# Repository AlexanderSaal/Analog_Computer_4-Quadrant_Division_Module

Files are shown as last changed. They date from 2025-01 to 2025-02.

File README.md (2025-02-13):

# Analog Computer - 4-Quadrant Division Module
---

This repository provides a 4-Quadrant Division Module for analog computing applications. The design incorporates two independent 4-Quadrant Division circuits, each equipped with an output signal indicator and overload indicator to monitor operation. \
 The overload indicator activates if the output exceeds the machine unit of $\pm10V$ and the output signal indicator is red or green proportional to the negative or positive output voltage. This display enables easy diagnostic of an analog computing patch.

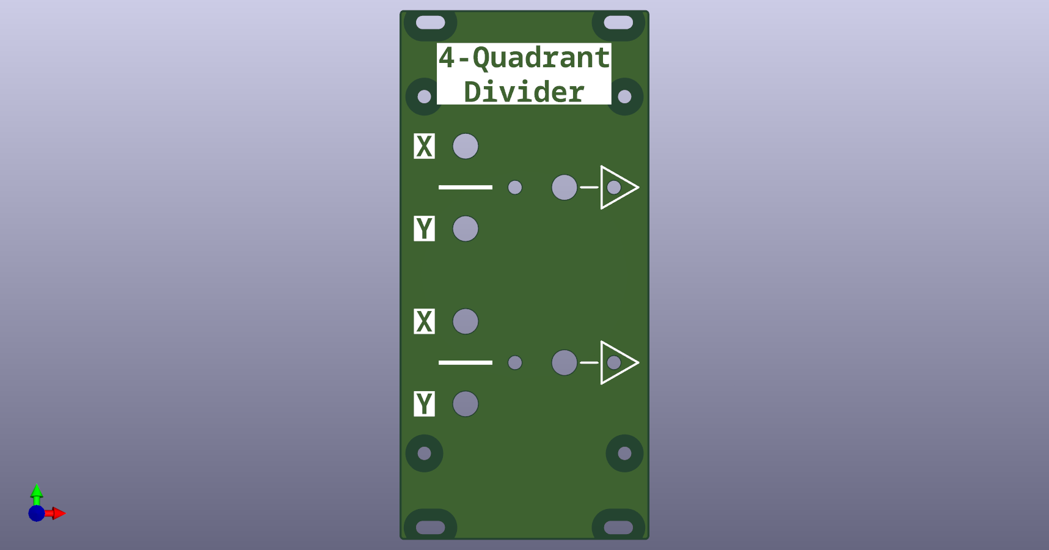
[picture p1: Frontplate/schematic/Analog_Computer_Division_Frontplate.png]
Front view of the Division Module


## Module Schematic

The schematic is divided into multiple sections for the ease of understanding. All functional modules like power management, division and error-indication have their own page in the circuit diagram.

<ins> 4-Quadrant Divider: </ins>\
The division is accomplished by having the multiplier in the feedback path of an operational amplifier, thus solving for $-X/|Y|$. To cover all 4 Quadrants of the input, we first have a section to get the absolute Value of of $Y$, which is fed into the division. The output then corrects for the sign of the input $Y$ and inverts the signal when needed. Thus the Output is $X/Y$, covering all 4 Quadrants of the input. To enable easy diagnostic and debugging of an analog patch, the LED indicator displays the polarity and size of the output signal.

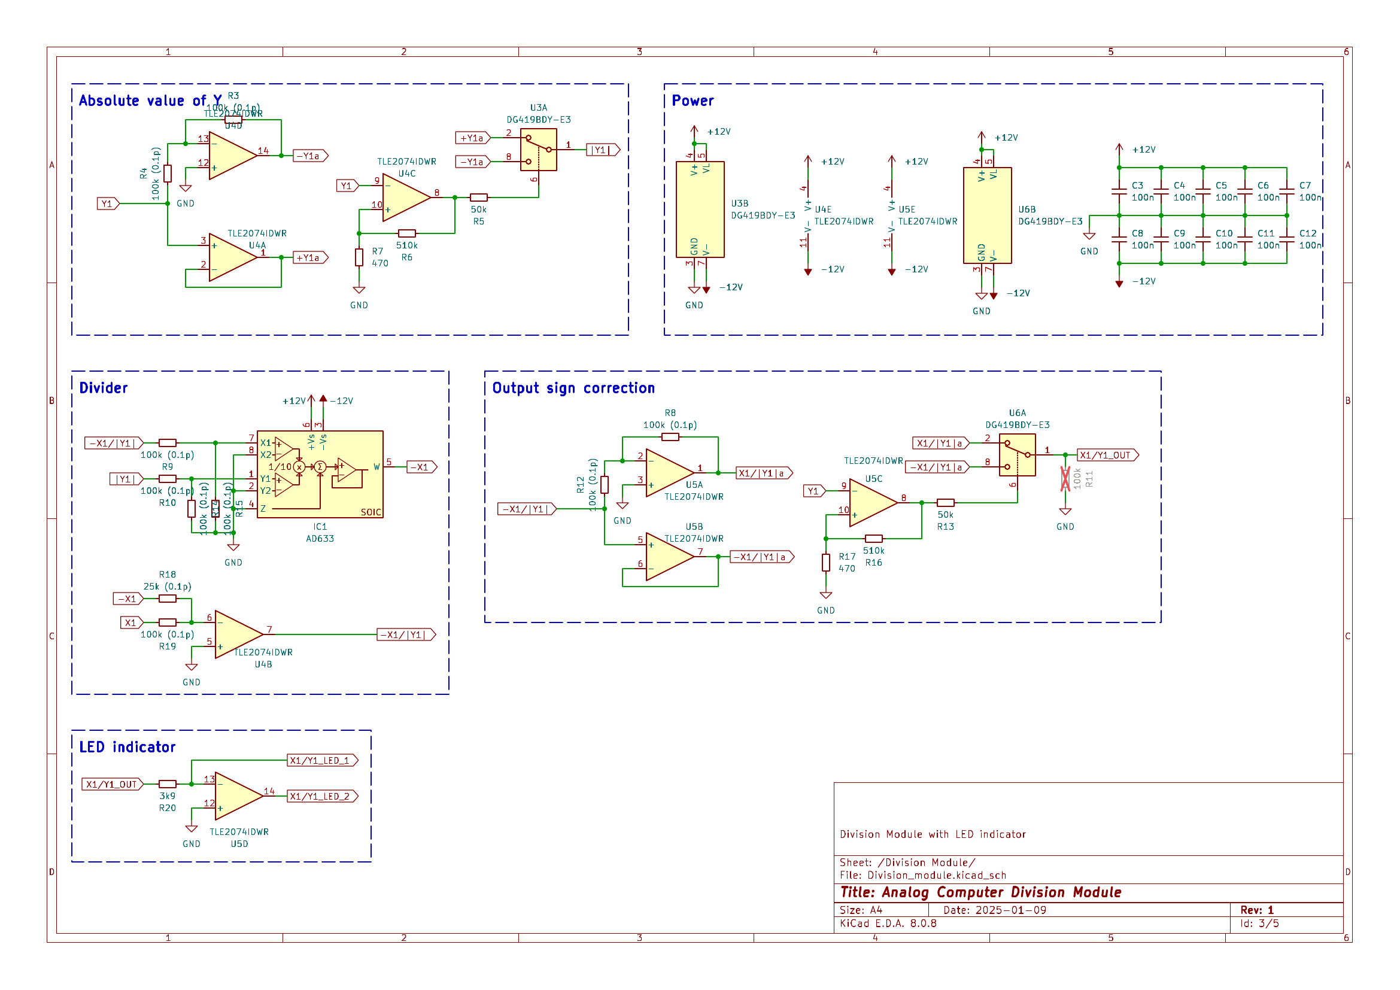
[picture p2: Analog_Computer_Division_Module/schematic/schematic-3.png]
Schematic of the Division Module Circuit implementation of the Division Module


<ins> Overload Indicator: </ins>\
The output signal of each seperate division circuit is compared to a reference voltage of $+10V$ and $-10V$. A red LED indicates the value of a division is exceeding the machine value of $\pm10V$. Which can easiliy happen when the absolute value of $Y$ gets small.

The Error Indicator for each individual Output takes a lot of extra space and components, but I consider it worth it for error hunting in an analog patch.

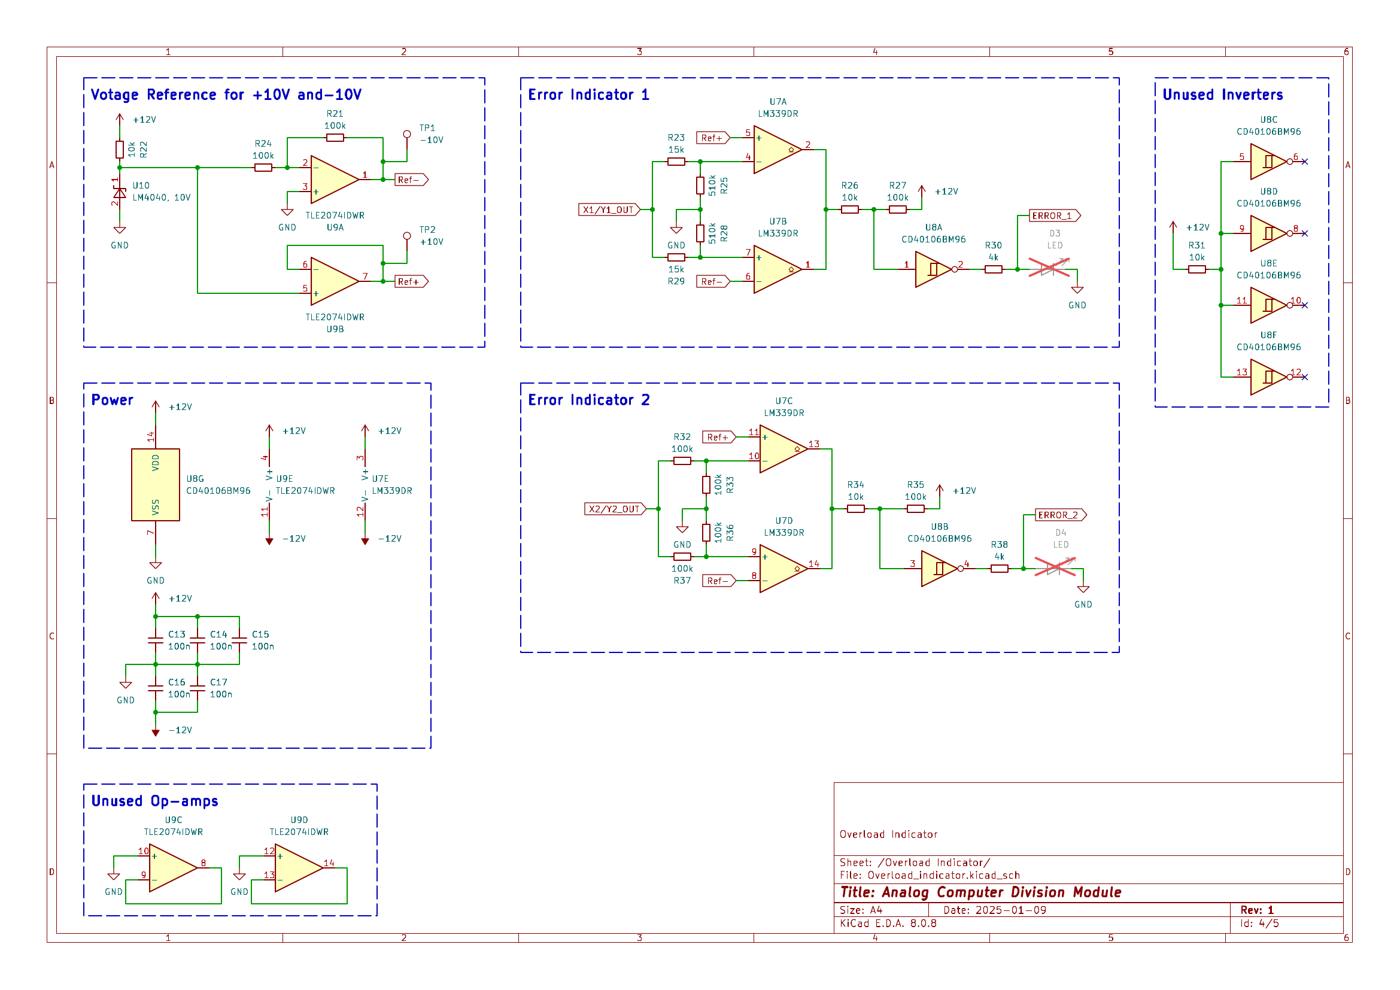
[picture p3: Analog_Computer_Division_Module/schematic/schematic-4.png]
Schematic of the Error Indicator Circuit implementation of the Error Indicator


<ins> References: </ins>\
The circuit is mostly based on the [THAT](https://the-analog-thing.org/) of [Anabrid GmbH](https://anabrid.com/), which has its circuit diagram openly available at their github repository [Anabrid](https://github.com/anabrid/the-analog-thing/tree/main). Also a special mention goes to Michael Koch who has put together a large collection of analog computing circuits in his [book on the THAT Analog Computer](http://www.astro-electronic.de/THAT_Analog_Computer_Book.pdf).

## BOM

**<ins>Main Module:</ins>** 

|Reference |Value |Footprint |QUANTITY|
|---|---|---|---|
|C1,C2 |10u |1206 / 3216Metric |2 |
|C3-C27 |100n |1206 / 3216Metric |25 |
|D1 |12V_GREEN |1206 / 3216Metric |1 |
|D2 |-12V_RED |1206 / 3216Metric |1 |
|IC1,IC2 |AD633 |SOIC-8 |2 |
|J1 |Conn_01x14_Pin |PinHeader_1x14_P2.54mm_Vertical|1 |
|J2 |Conn_02x05_Odd_Even|PinHeader_2x05_P2.54mm_Vertical|1 |
|Q1 |PMV250EPEA |SOT-23 |1 |
|Q2 |PMV450ENEA |SOT-23 |1 |
|R1,R2 |5k6 |1206 / 3216Metric |2 |
|R3,R4,R8-R10,R12,R14,R15,R19,R39,R40,R44-R46,R48,R50,R51,R55|100k (0.1p) |1206 / 3216Metric |18 |
|R5,R13,R41,R49 |50k |1206 / 3216Metric |4 |
|R6,R16,R25,R28,R42,R52 |510k |1206 / 3216Metric |6 |
|R7,R17,R43,R53 |470 |1206 / 3216Metric |4 |
|R18,R54 |25k (0.1p) |1206 / 3216Metric |2 |
|R20,R56 |3k9 |1206 / 3216Metric |2 |
|R21,R24,R27,R32,R33,R35-R37 |100k |1206 / 3216Metric |8 |
|R22,R26,R31,R34 |10k |1206 / 3216Metric |4 |
|R23,R29 |15k |1206 / 3216Metric |2 |
|R30,R38 |4k |1206 / 3216Metric |2 |
|U1,U2 |VCAN16A2 |SOT23-3 |2 |
|U3,U6,U11,U14 |DG419BDY-E3 |SOIC-8 |4 |
|U4,U5,U9,U12,U13 |TLE2074IDWR |SOIC-14 |5 |
|U7 |LM339DR |SOIC-14 |1 |
|U8 |CD40106BM96 |SOIC-14 |1 |
|U10 |LM4040, 10V |SOT-23 |1 |

**<ins>Middleplate:</ins>**

|Reference |Value |Footprint |QUANTITY|
|---|---|---|---|
|D1 |IND_X1/Y1 |LED_D3.0mm_FlatTop |1 |
|D2 |ERROR_1 |LED_D3.0mm_FlatTop |1 |
|D3 |IND_X2/Y2 |LED_D3.0mm_FlatTop |1 |
|D4 |ERROR_2 |LED_D3.0mm_FlatTop |1 |
|J1 |Conn_01x14_Socket  |PinSocket_1x14_P2.54mm_Vertical|1 |
|U1-U3 |VCAN16A2-03S-E3-08 |SOT23-3 |3 |

## List of special Components:

- OP-amp: [TLE2074IDWR](https://www.digikey.de/en/products/detail/texas-instruments/TLE2074IDWR/2799317) (Upgrade of the [TL074HIDR](https://www.digikey.de/en/products/detail/texas-instruments/TL074HIDR/13563033))
- analog IC switch: [DG456EY](https://www.digikey.de/en/products/detail/vishay-siliconix/DG456EY-T1-E3/1850020), [DG419BDY-E3](https://www.digikey.de/en/products/detail/vishay-siliconix/DG419BDY-E3/2621756), [DG403DYZ](https://www.digikey.de/en/products/detail/renesas-electronics-corporation/DG403DYZ/936160)
- 10V voltage reference: [LM4040CIM3-10.0/NOPB](https://www.digikey.de/en/products/detail/texas-instruments/LM4040CIM3-10-0-NOPB/363991)
- comparator: [LM339DR](https://www.digikey.de/en/products/detail/texas-instruments/LM339DR/276657)
- logic inverter: [CD40106BM96](https://www.digikey.de/en/products/detail/texas-instruments/CD40106BM96/525858)

Altnernatives to consider:
- Multiplier: [AD633JRZ](https://www.digikey.de/en/products/detail/analog-devices-inc/AD633JRZ/617831) to [AD835ARZ](https://www.digikey.de/en/products/detail/analog-devices-inc/AD835ARZ-REEL7/621103)

## License

This work is published under the [CERN Open Hardware Licence Version 2 - Strongly Reciprocal](LICENSE)

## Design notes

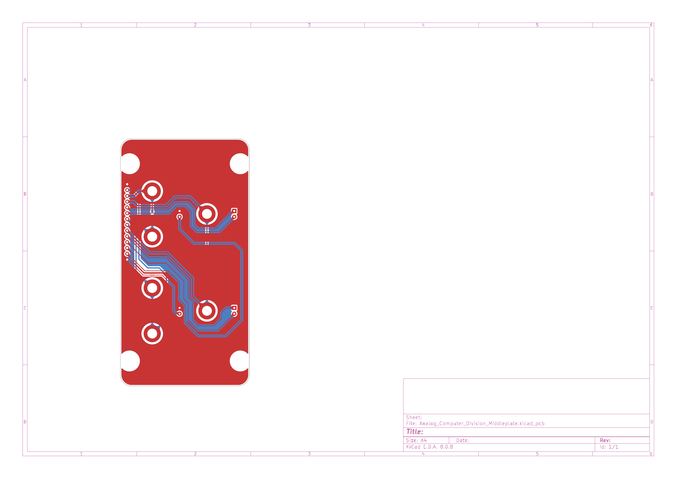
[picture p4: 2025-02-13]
Middleplate/schematic/PCB-1.png

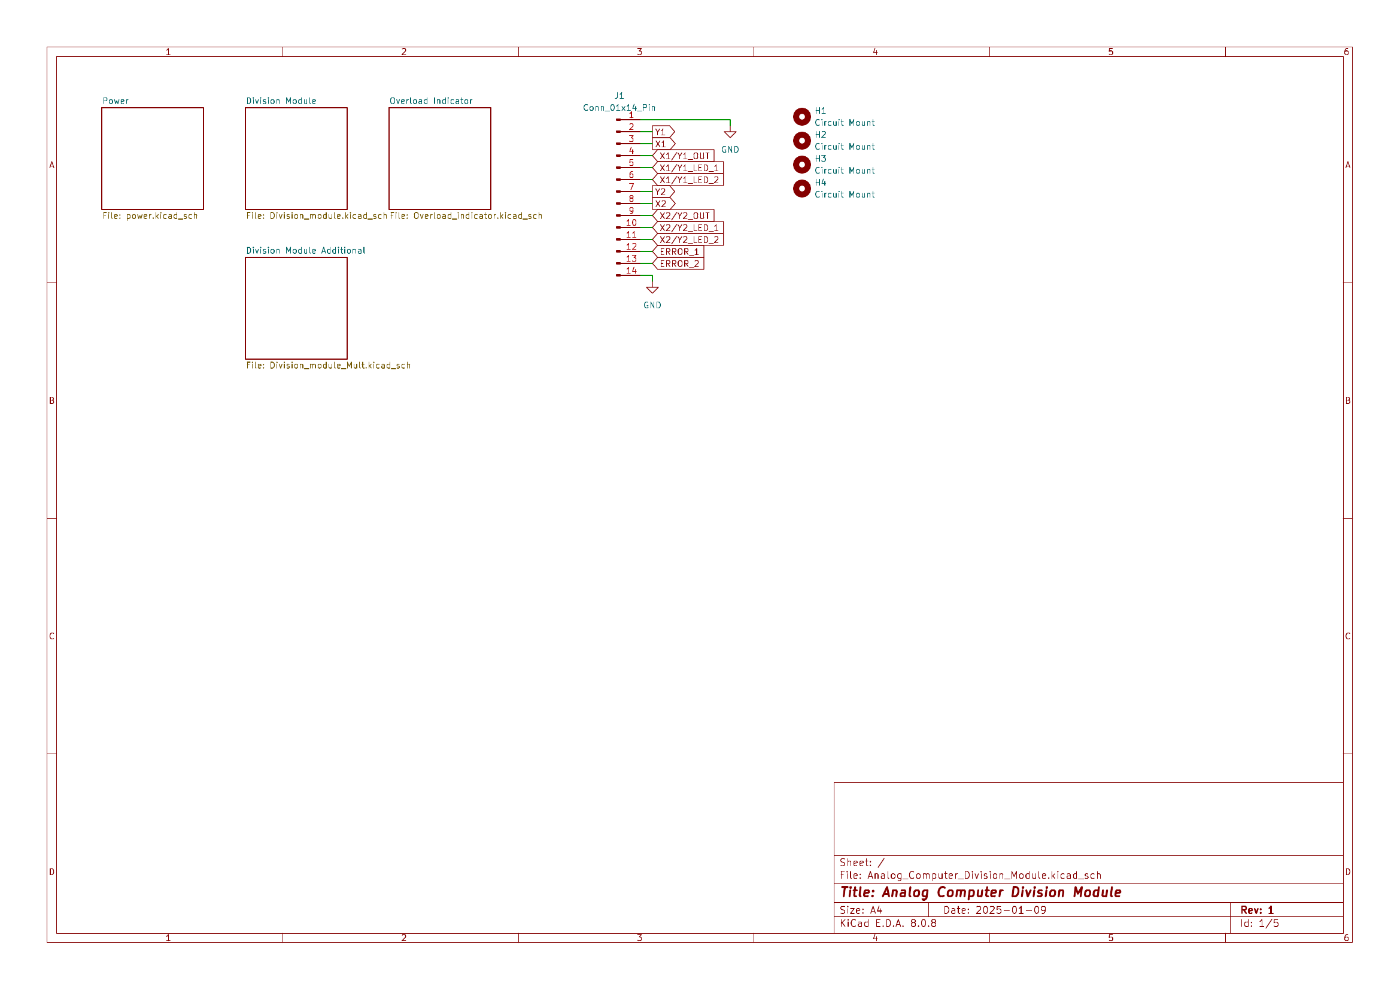
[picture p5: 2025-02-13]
Analog_Computer_Division_Module/schematic/schematic-1.png

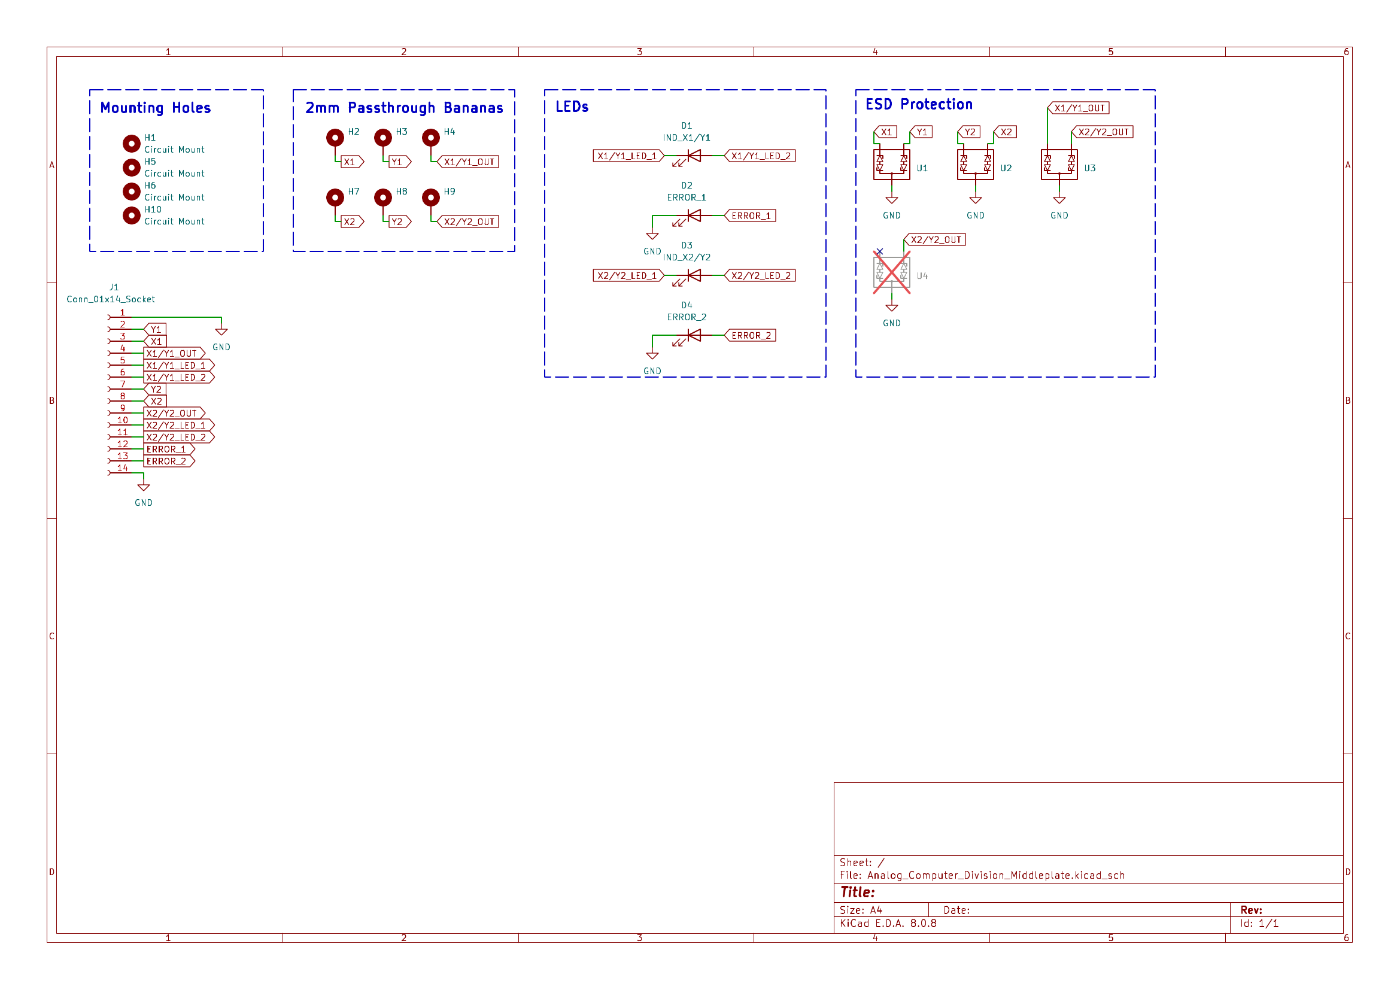
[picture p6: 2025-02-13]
Middleplate/schematic/schematic-1.png

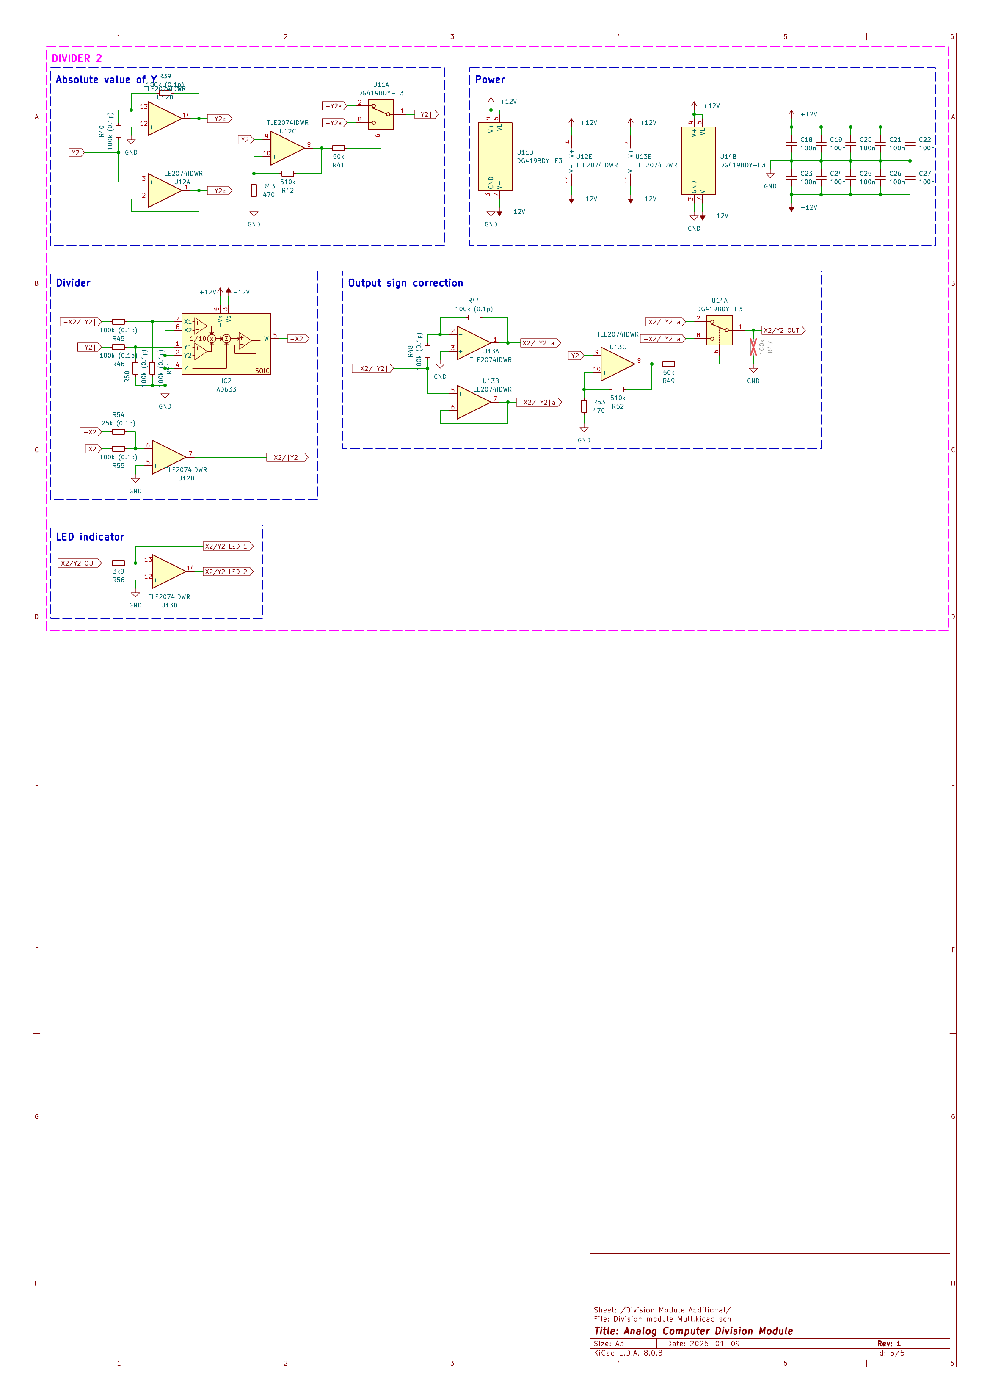
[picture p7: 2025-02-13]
Analog_Computer_Division_Module/schematic/schematic-5.png

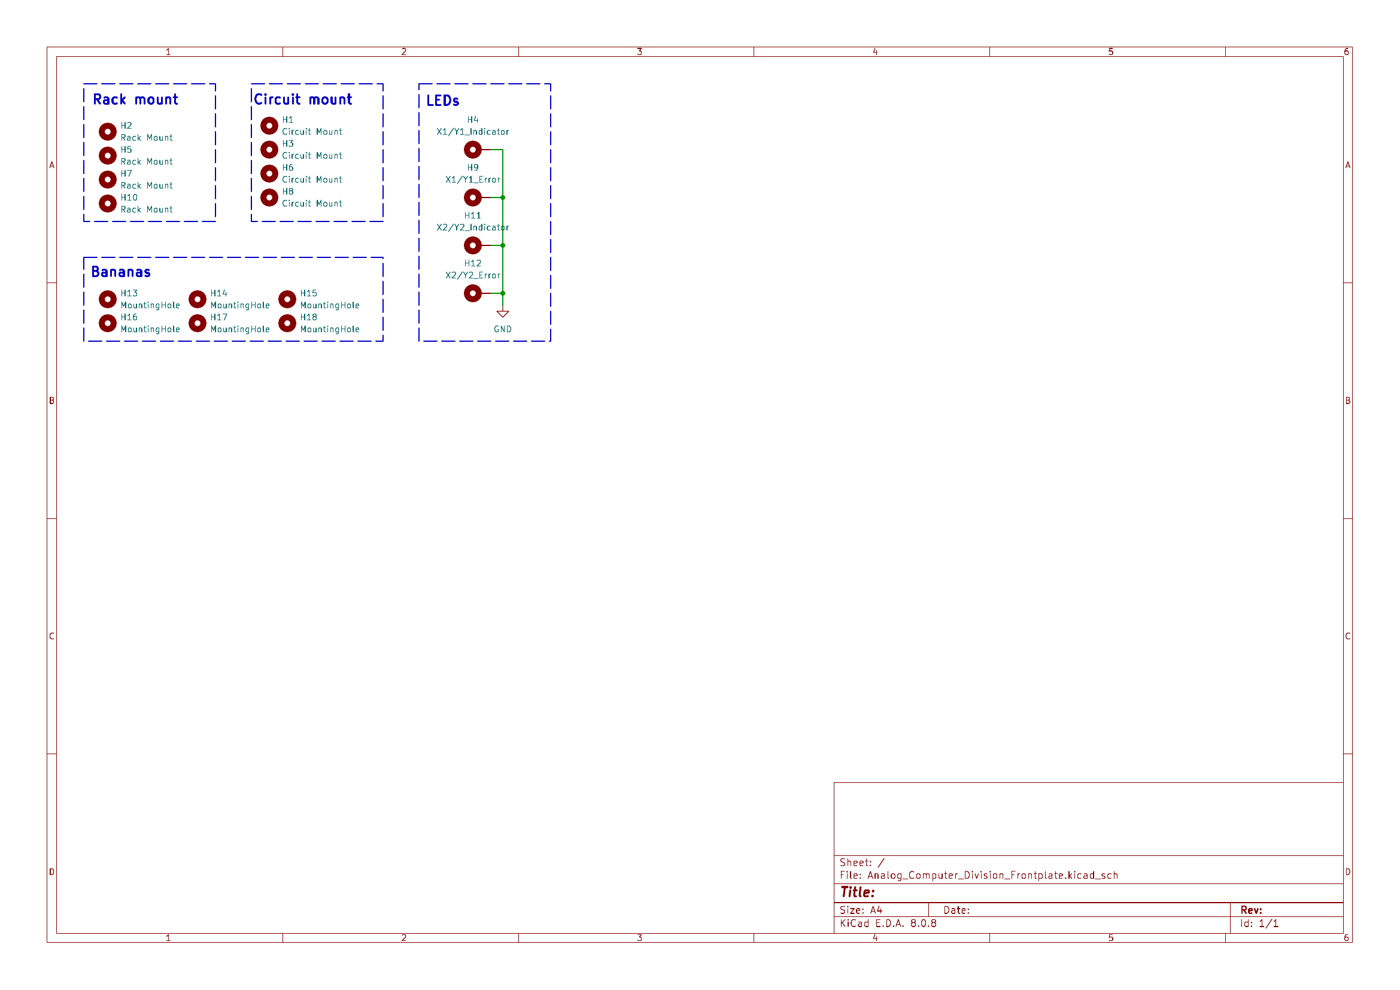
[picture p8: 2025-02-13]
Frontplate/schematic/schematic-1.png

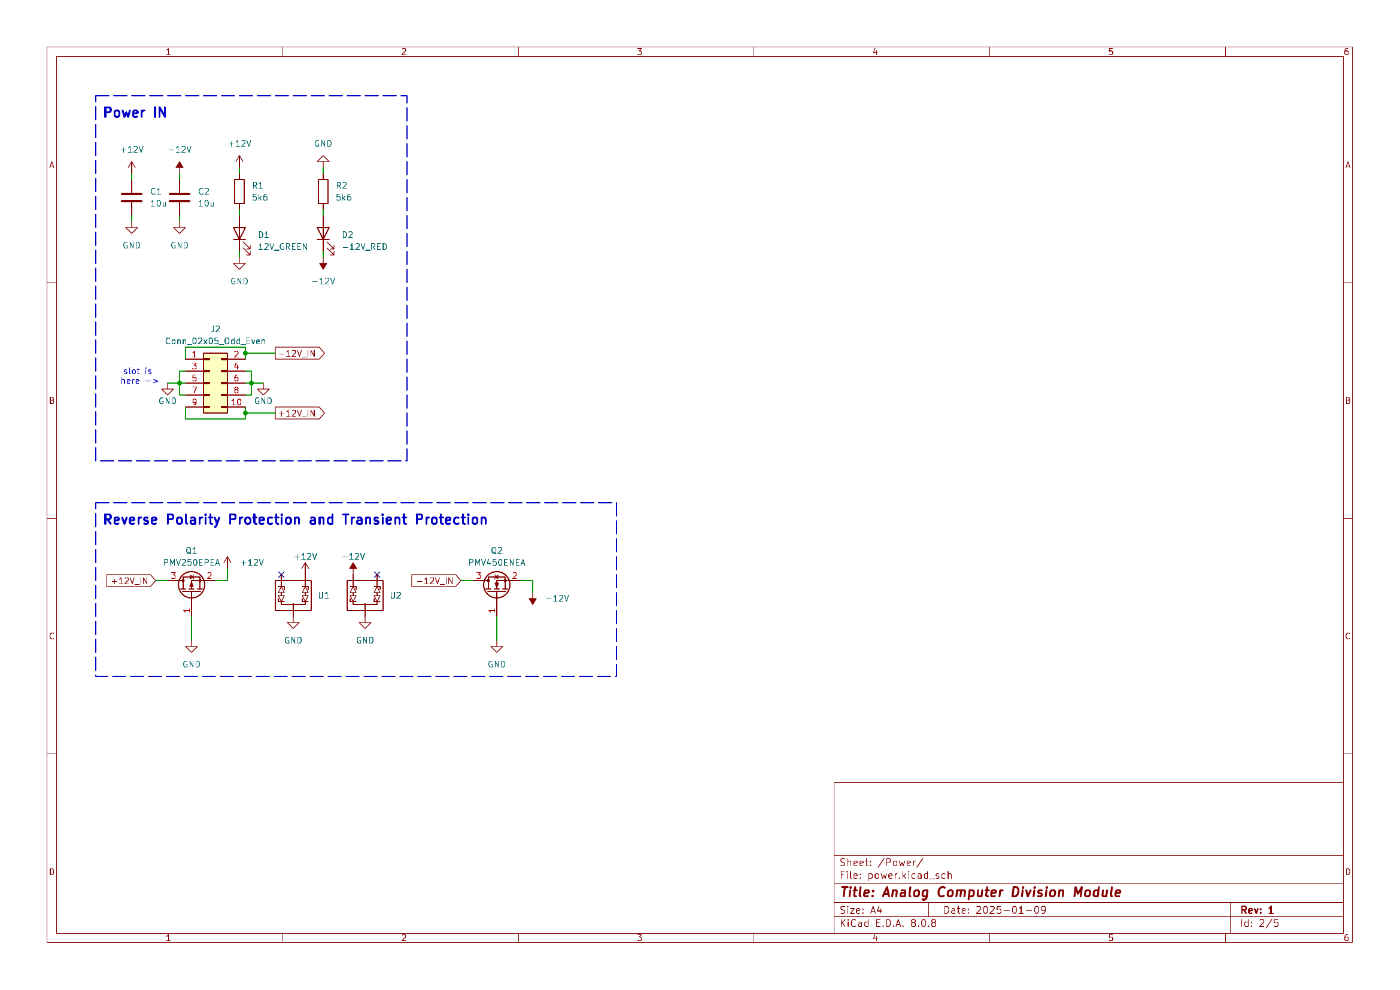
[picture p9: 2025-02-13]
Analog_Computer_Division_Module/schematic/schematic-2.png

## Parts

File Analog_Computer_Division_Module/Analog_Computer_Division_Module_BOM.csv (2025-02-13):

Reference | Value | Footprint | QUANTITY
C1,C2 | 10u | Capacitor_SMD:C_1206_3216Metric_Pad1.33x1.80mm_HandSolder | 2
C3-C27 | 100n | Capacitor_SMD:C_1206_3216Metric_Pad1.33x1.80mm_HandSolder | 25
D1 | 12V_GREEN | LED_SMD:LED_1206_3216Metric | 1
D2 | -12V_RED | LED_SMD:LED_1206_3216Metric | 1
IC1,IC2 | AD633 | Package_SO:SOIC-8_3.9x4.9mm_P1.27mm | 2
J1 | Conn_01x14_Pin | Connector_PinHeader_2.54mm:PinHeader_1x14_P2.54mm_Vertical | 1
J2 | Conn_02x05_Odd_Even | Connector_PinHeader_2.54mm:PinHeader_2x05_P2.54mm_Vertical | 1
Q1 | PMV250EPEA | Package_TO_SOT_SMD:SOT-23_Handsoldering | 1
Q2 | PMV450ENEA | Package_TO_SOT_SMD:SOT-23_Handsoldering | 1
R1,R2 | 5k6 | Resistor_SMD:R_1206_3216Metric_Pad1.30x1.75mm_HandSolder | 2
R3,R4,R8-R10,R12,R14,R15,R19,R39,R40,R44-R46,R48,R50,R51,R55 | 100k (0.1p) | Resistor_SMD:R_1206_3216Metric_Pad1.30x1.75mm_HandSolder | 18
R5,R13,R41,R49 | 50k | Resistor_SMD:R_1206_3216Metric_Pad1.30x1.75mm_HandSolder | 4
R6,R16,R25,R28,R42,R52 | 510k | Resistor_SMD:R_1206_3216Metric_Pad1.30x1.75mm_HandSolder | 6
R7,R17,R43,R53 | 470 | Resistor_SMD:R_1206_3216Metric_Pad1.30x1.75mm_HandSolder | 4
R18,R54 | 25k (0.1p) | Resistor_SMD:R_1206_3216Metric_Pad1.30x1.75mm_HandSolder | 2
R20,R56 | 3k9 | Resistor_SMD:R_1206_3216Metric_Pad1.30x1.75mm_HandSolder | 2
R21,R24,R27,R32,R33,R35-R37 | 100k | Resistor_SMD:R_1206_3216Metric_Pad1.30x1.75mm_HandSolder | 8
R22,R26,R31,R34 | 10k | Resistor_SMD:R_1206_3216Metric_Pad1.30x1.75mm_HandSolder | 4
R23,R29 | 15k | Resistor_SMD:R_1206_3216Metric_Pad1.30x1.75mm_HandSolder | 2
R30,R38 | 4k | Resistor_SMD:R_1206_3216Metric_Pad1.30x1.75mm_HandSolder | 2
U1,U2 | VCAN16A2 | analog_computing:VCAN16A2-03S-E3-08 | 2
U3,U6,U11,U14 | DG419BDY-E3 | Package_SO:SOIC-8_3.9x4.9mm_P1.27mm | 4
U4,U5,U9,U12,U13 | TLE2074IDWR | Package_SO:SOIC-14_3.9x8.7mm_P1.27mm | 5
U7 | LM339DR | Package_SO:SOIC-14_3.9x8.7mm_P1.27mm | 1
U8 | CD40106BM96 | Package_SO:SOIC-14_3.9x8.7mm_P1.27mm | 1
U10 | LM4040, 10V | Package_TO_SOT_SMD:SOT-23 | 1

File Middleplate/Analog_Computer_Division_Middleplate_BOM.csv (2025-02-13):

Reference | Value | Footprint | QUANTITY
D1 | IND_X1/Y1 | LED_THT:LED_D3.0mm_FlatTop | 1
D2 | ERROR_1 | LED_THT:LED_D3.0mm_FlatTop | 1
D3 | IND_X2/Y2 | LED_THT:LED_D3.0mm_FlatTop | 1
D4 | ERROR_2 | LED_THT:LED_D3.0mm_FlatTop | 1
J1 | Conn_01x14_Socket | Connector_PinSocket_2.54mm:PinSocket_1x14_P2.54mm_Vertical | 1
U1-U3 | VCAN16A2-03S-E3-08 | analog_computing:VCAN16A2-03S-E3-08 | 3

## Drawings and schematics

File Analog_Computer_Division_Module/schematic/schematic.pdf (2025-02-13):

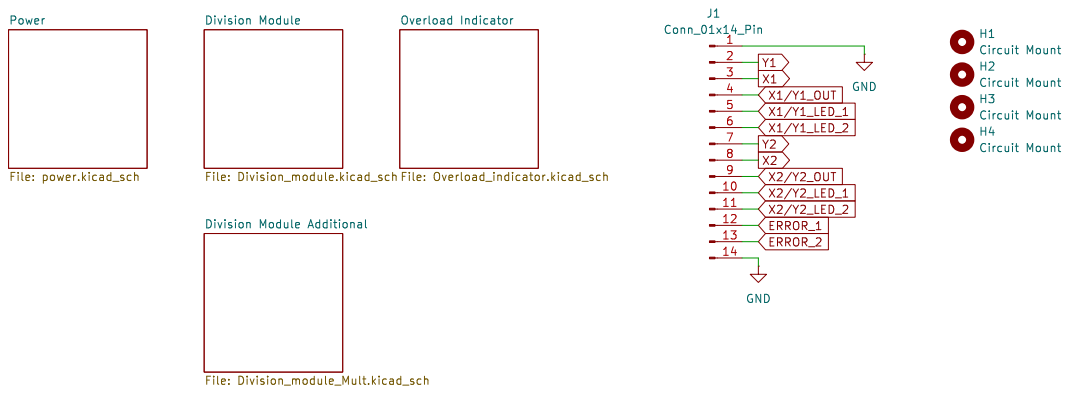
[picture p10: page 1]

File: Analog_Computer_Division_Module.kicad_sch Sheet: /
Id: 1/5 Title: Analog Computer Division Module

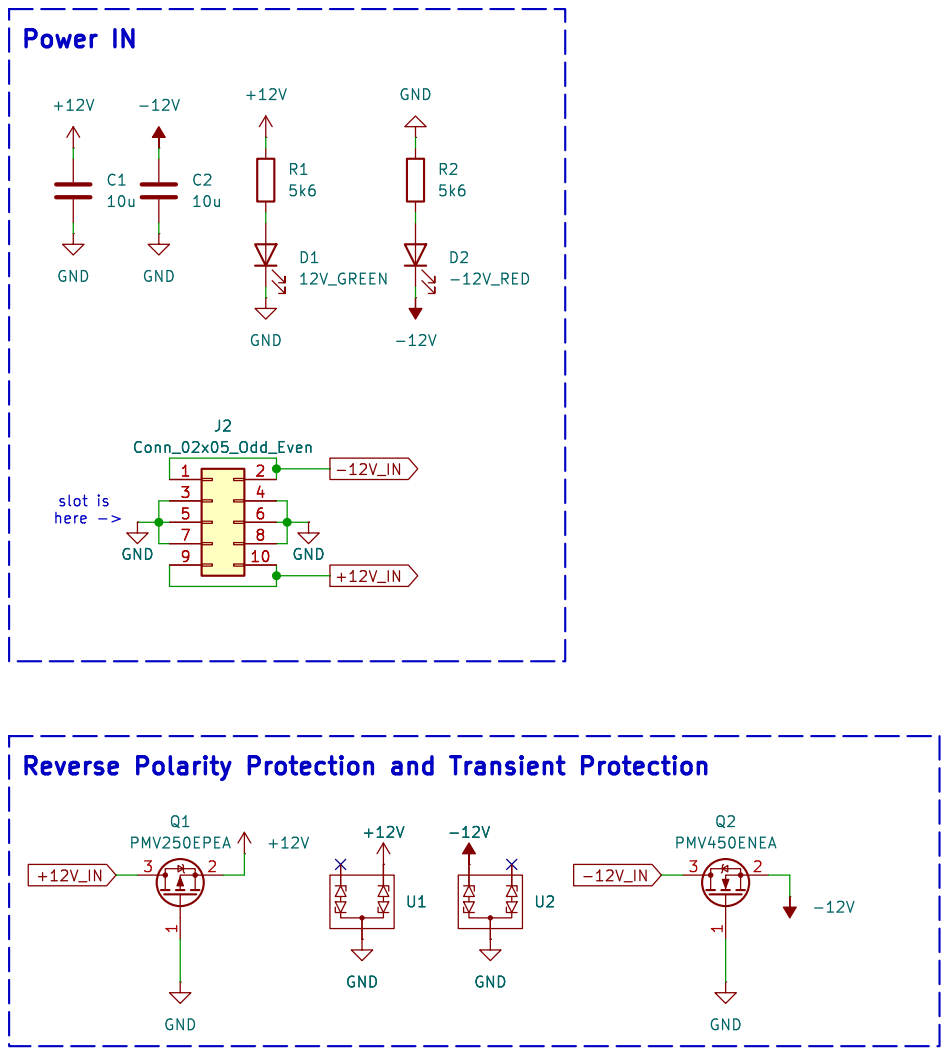
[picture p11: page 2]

File: power.kicad_sch Sheet: /Power/
Id: 2/5 Title: Analog Computer Division Module

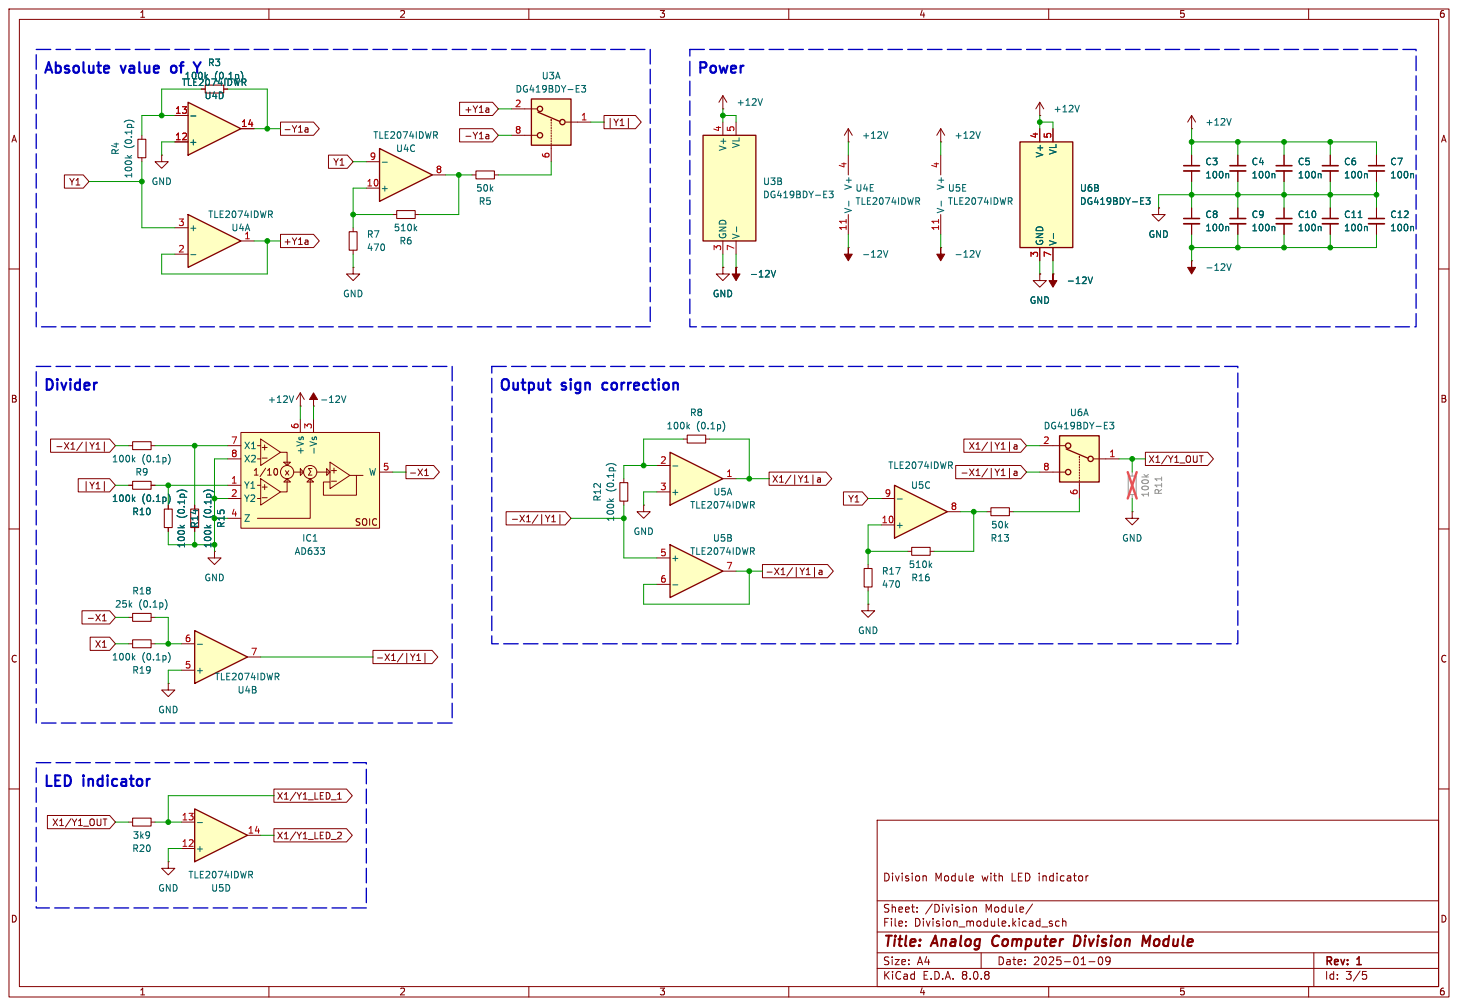
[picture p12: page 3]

Id: 3/5 Title: Analog Computer Division Module

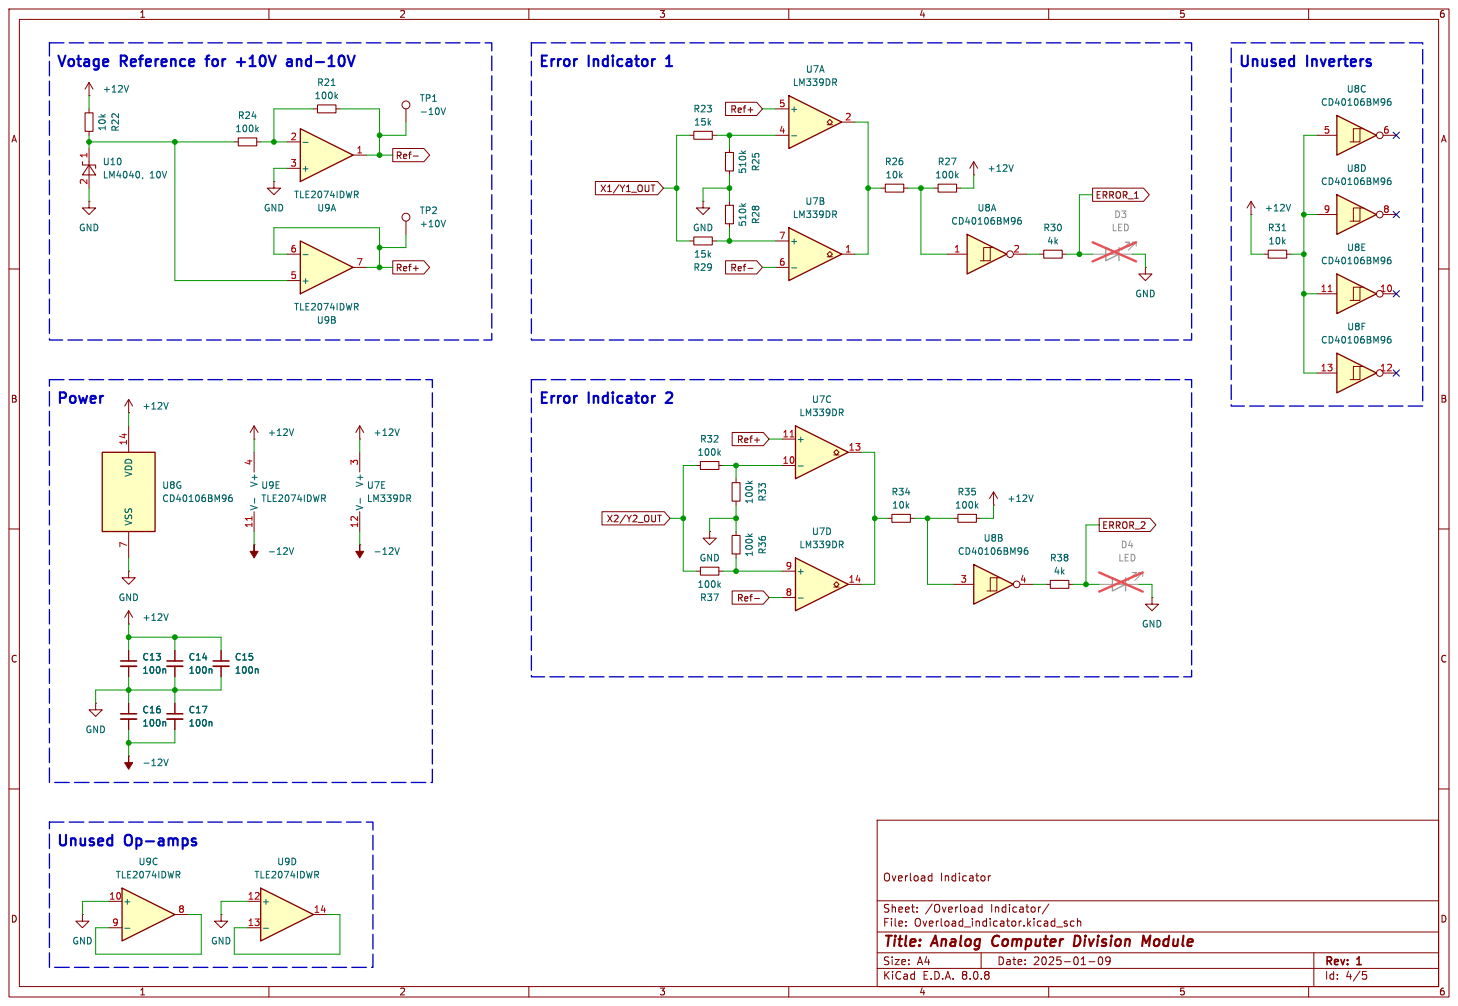
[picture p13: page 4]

Id: 4/5 Title: Analog Computer Division Module

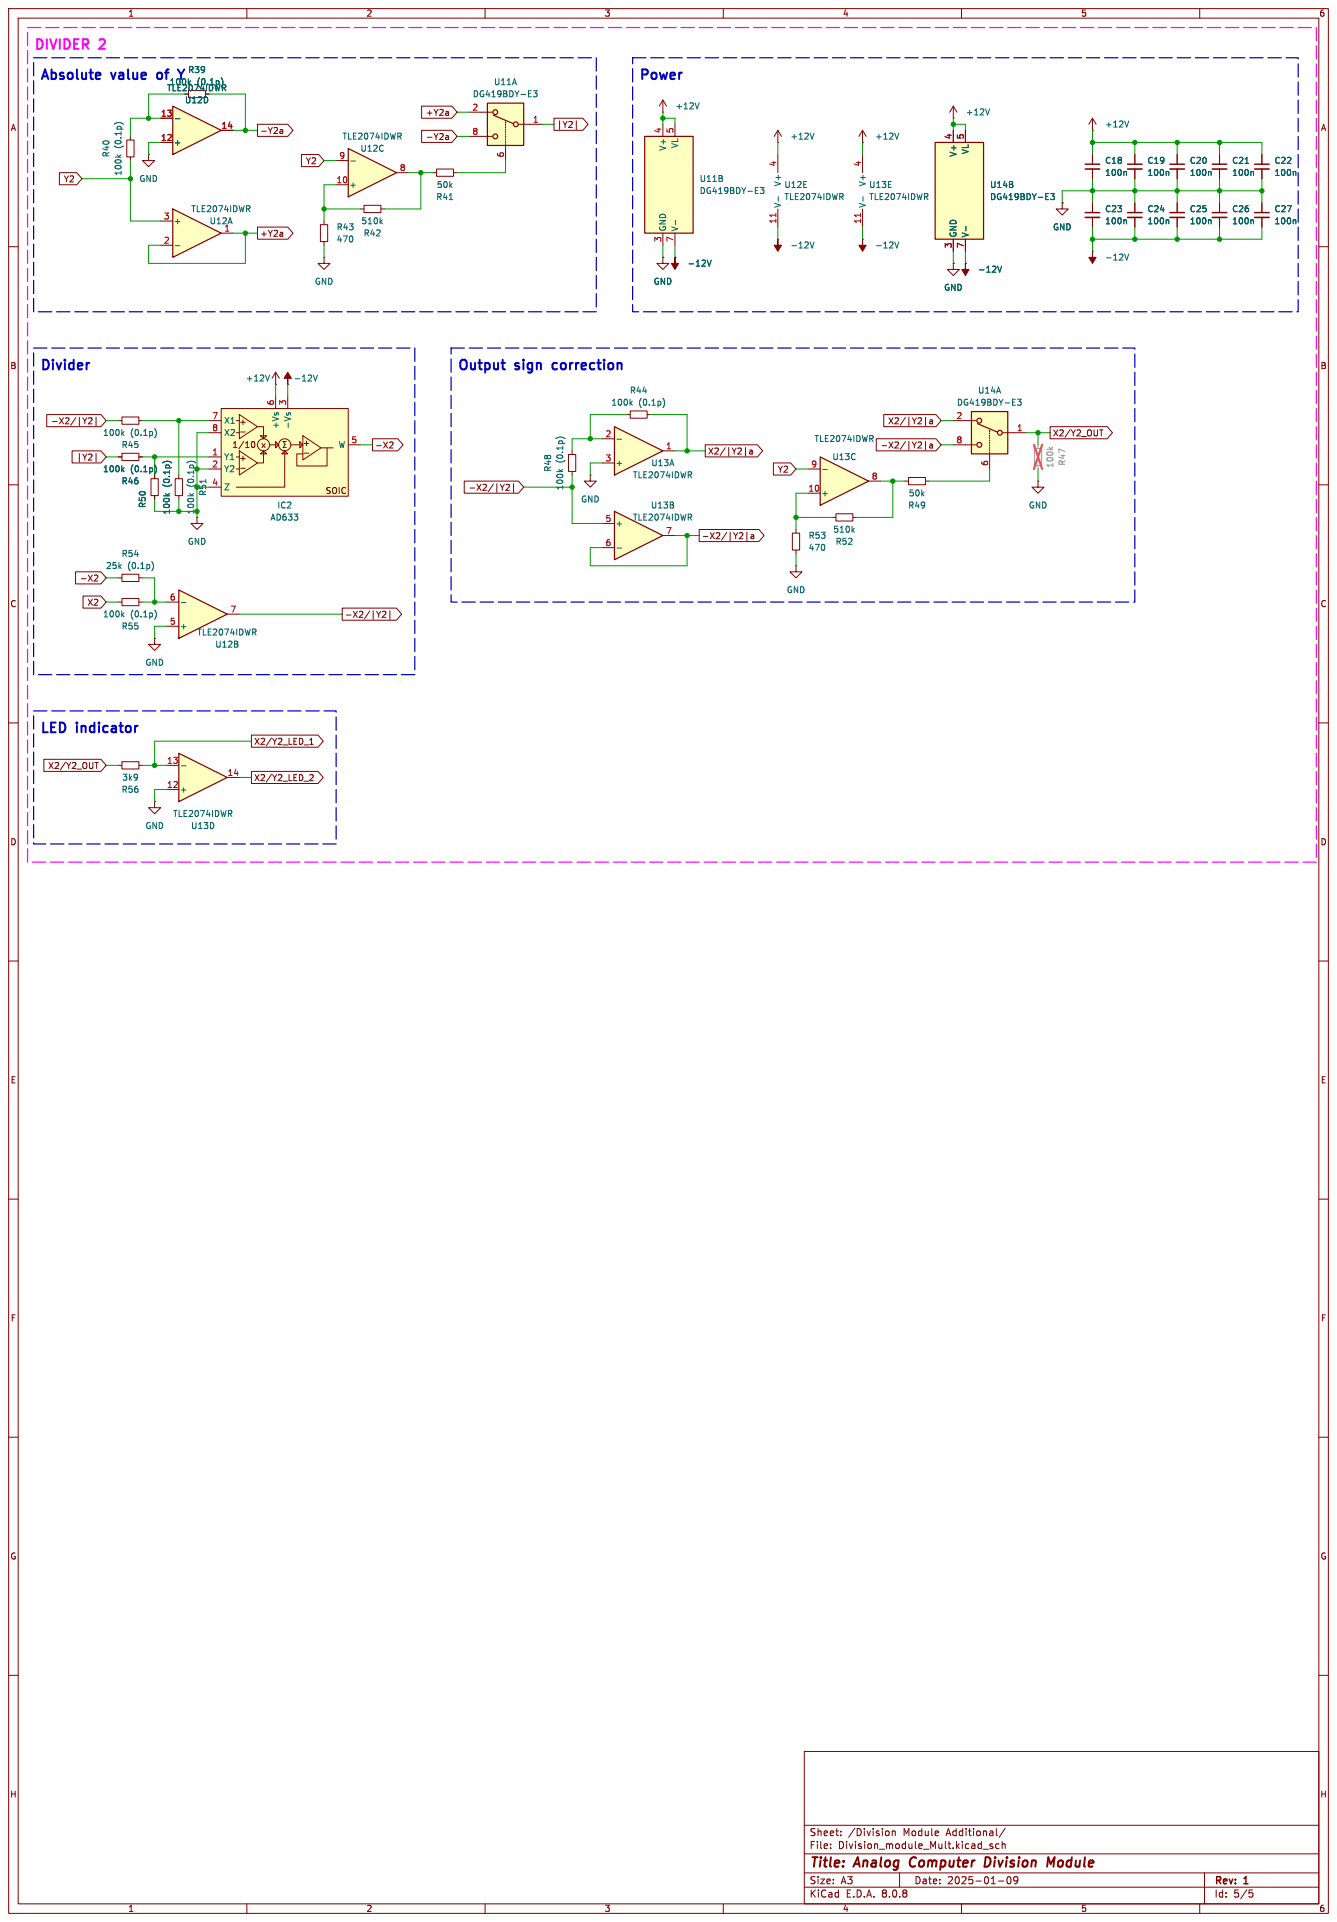
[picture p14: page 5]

Id: 5/5 Title: Analog Computer Division Module

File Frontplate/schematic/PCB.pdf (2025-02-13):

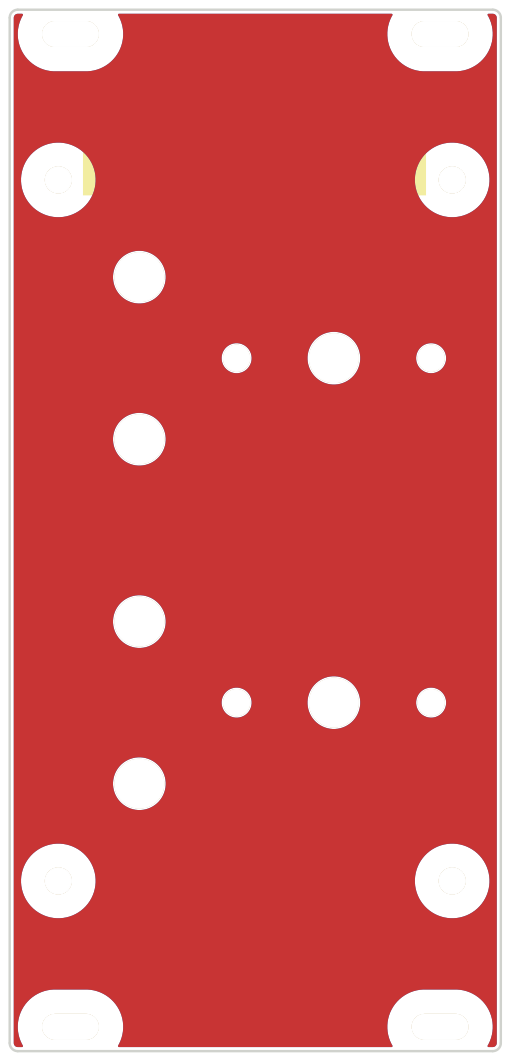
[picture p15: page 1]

Id: 1/1 Title: File: Analog_Computer_Division_Frontplate.kicad_pcb Sheet: JLCJLCJLCJLC

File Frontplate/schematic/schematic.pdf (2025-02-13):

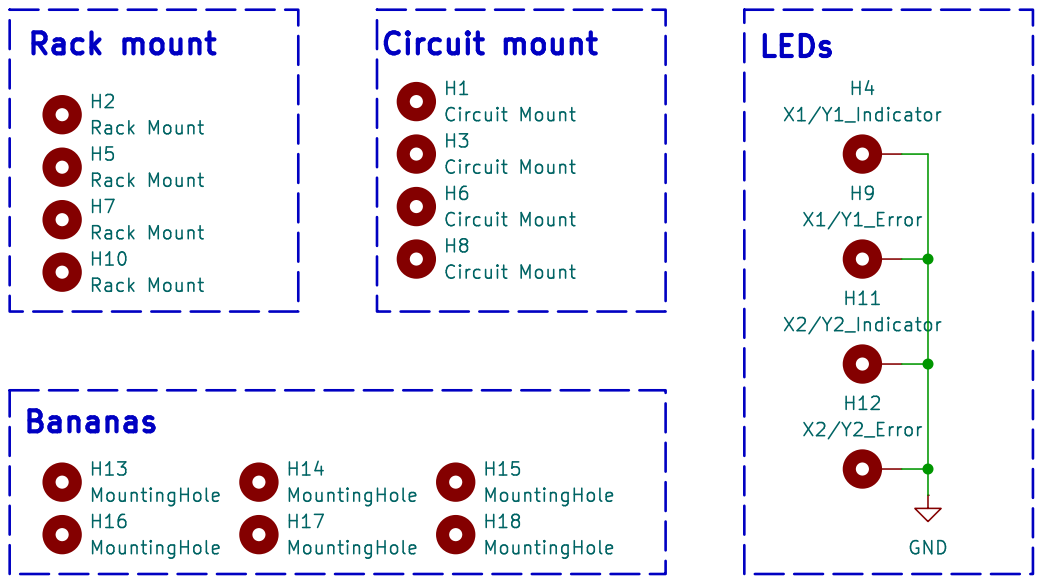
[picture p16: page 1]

Id: 1/1 Title: File: Analog_Computer_Division_Frontplate.kicad_sch Sheet: /

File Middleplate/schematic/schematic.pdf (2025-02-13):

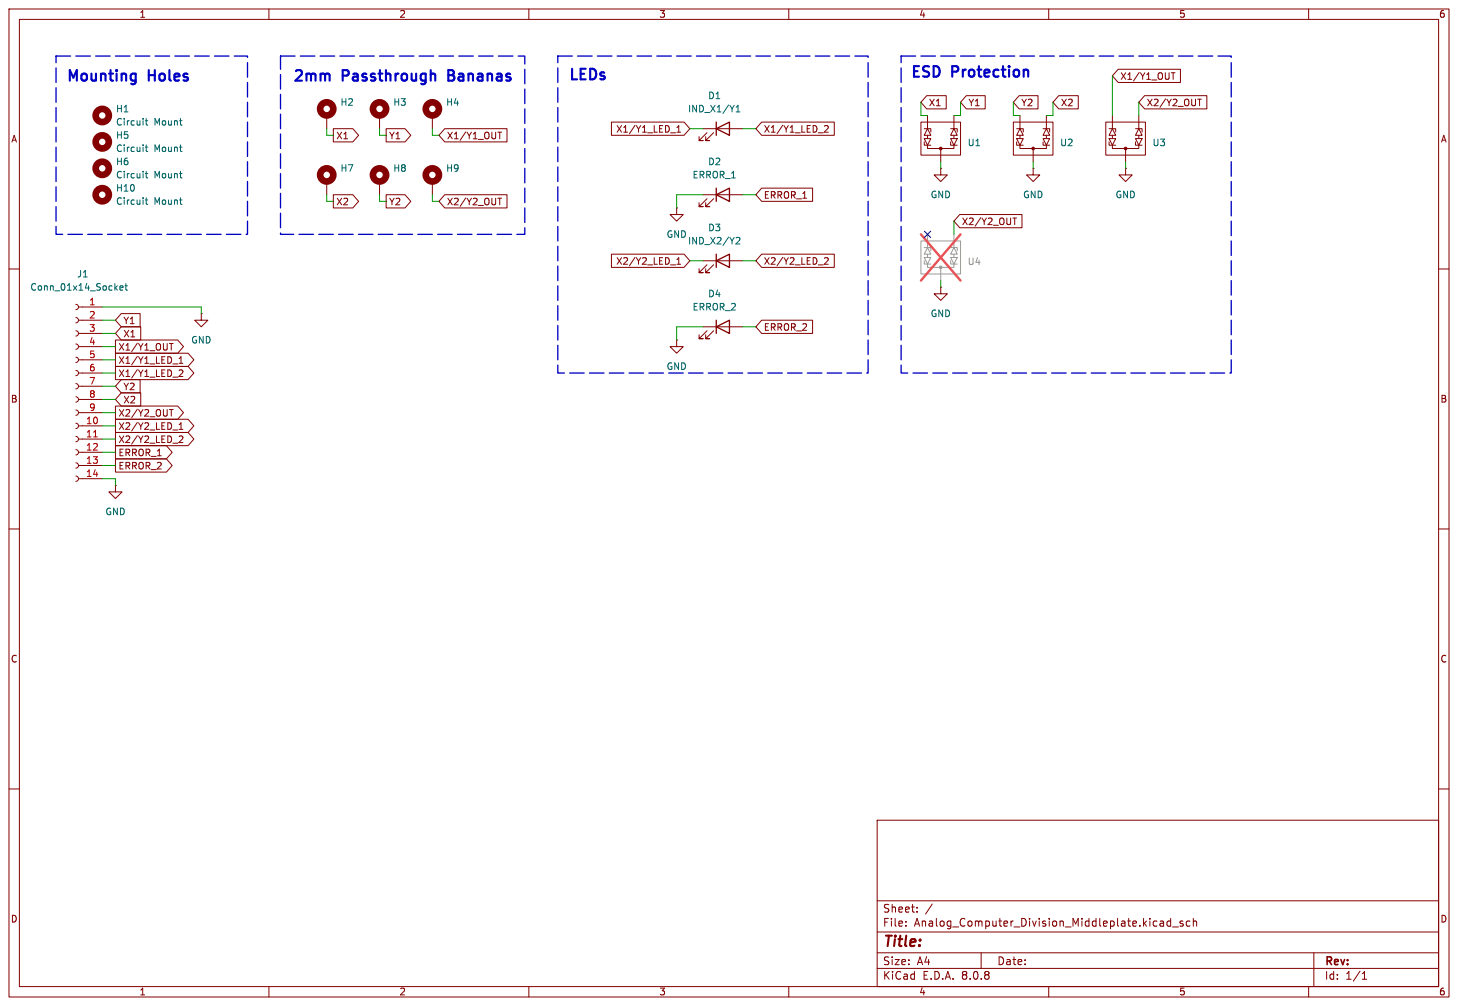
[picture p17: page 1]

U1 U4 GND GND GND GND

Id: 1/1 Title: File: Analog_Computer_Division_Middleplate.kicad_sch Sheet: /

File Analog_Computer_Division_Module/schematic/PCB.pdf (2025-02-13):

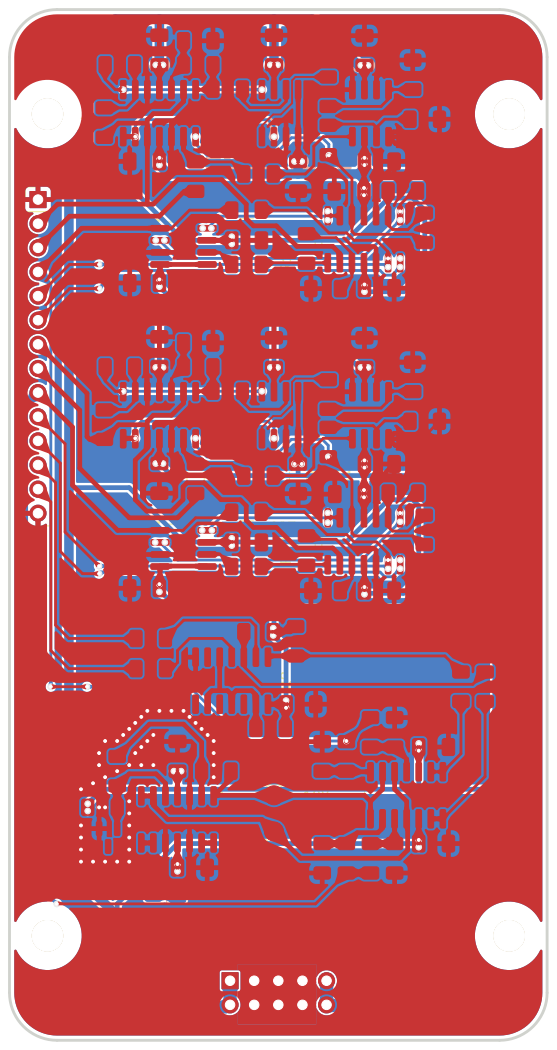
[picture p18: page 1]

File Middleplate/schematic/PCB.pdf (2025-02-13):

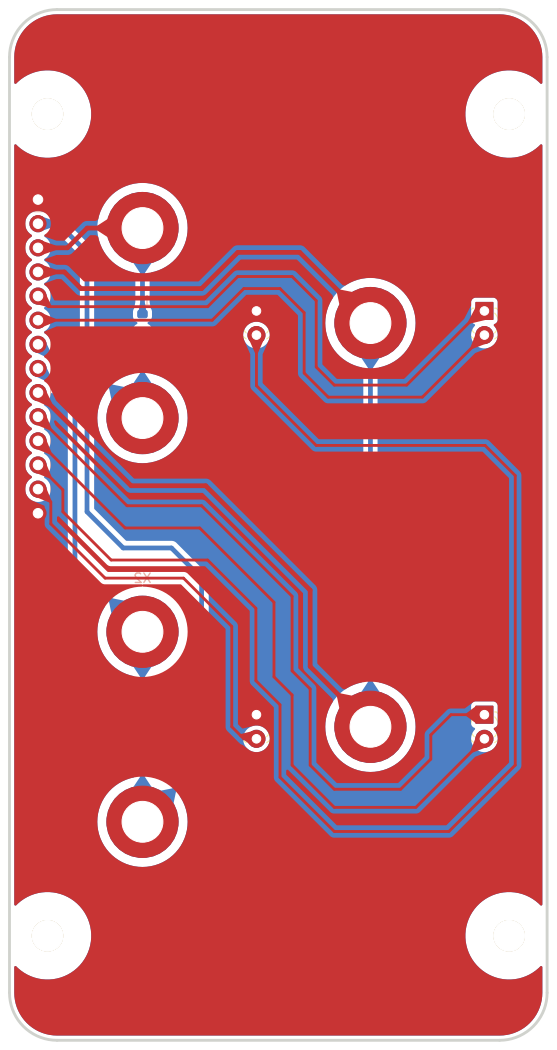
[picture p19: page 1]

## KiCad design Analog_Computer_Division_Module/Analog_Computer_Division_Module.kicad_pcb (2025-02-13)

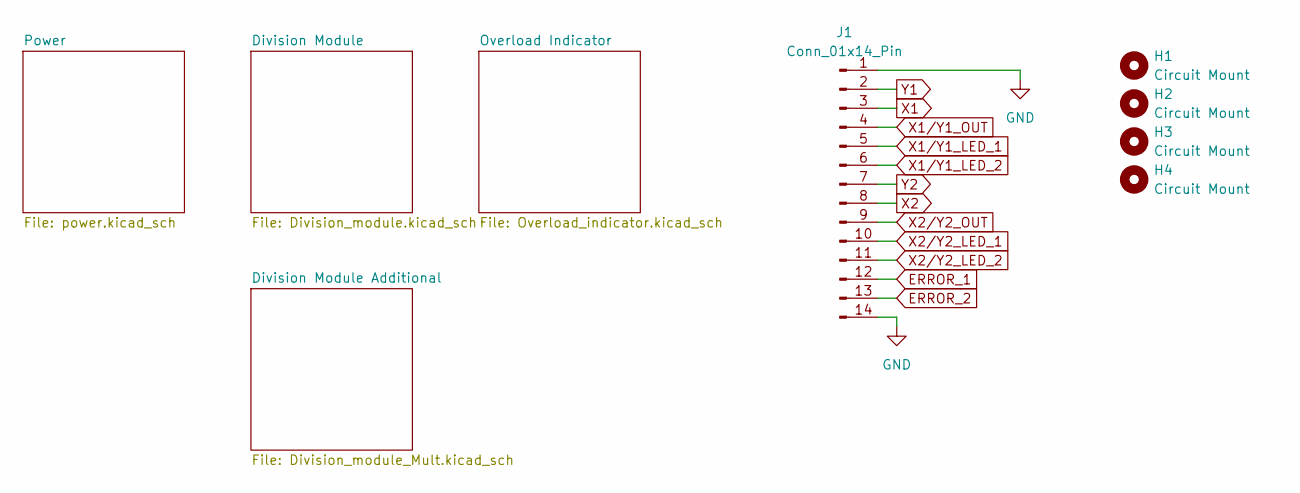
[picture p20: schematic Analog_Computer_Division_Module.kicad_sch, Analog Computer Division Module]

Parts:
H1, H2, H3, H4: Circuit Mount; MountingHole_3.2mm_M3_DIN965
J1: Conn_01x14_Pin; PinHeader_1x14_P2.54mm_Vertical

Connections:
ERROR_1: J1.12; also elsewhere on the board
ERROR_2: J1.13; also elsewhere on the board
GND: J1.1, J1.14; also elsewhere on the board
X1: J1.3; also elsewhere on the board
X1/Y1_LED_1: J1.5; also elsewhere on the board
X1/Y1_LED_2: J1.6; also elsewhere on the board
X1/Y1_OUT: J1.4; also elsewhere on the board
X2: J1.8; also elsewhere on the board
X2/Y2_LED_1: J1.10; also elsewhere on the board
X2/Y2_LED_2: J1.11; also elsewhere on the board
X2/Y2_OUT: J1.9; also elsewhere on the board
Y1: J1.2; also elsewhere on the board
Y2: J1.7; also elsewhere on the board

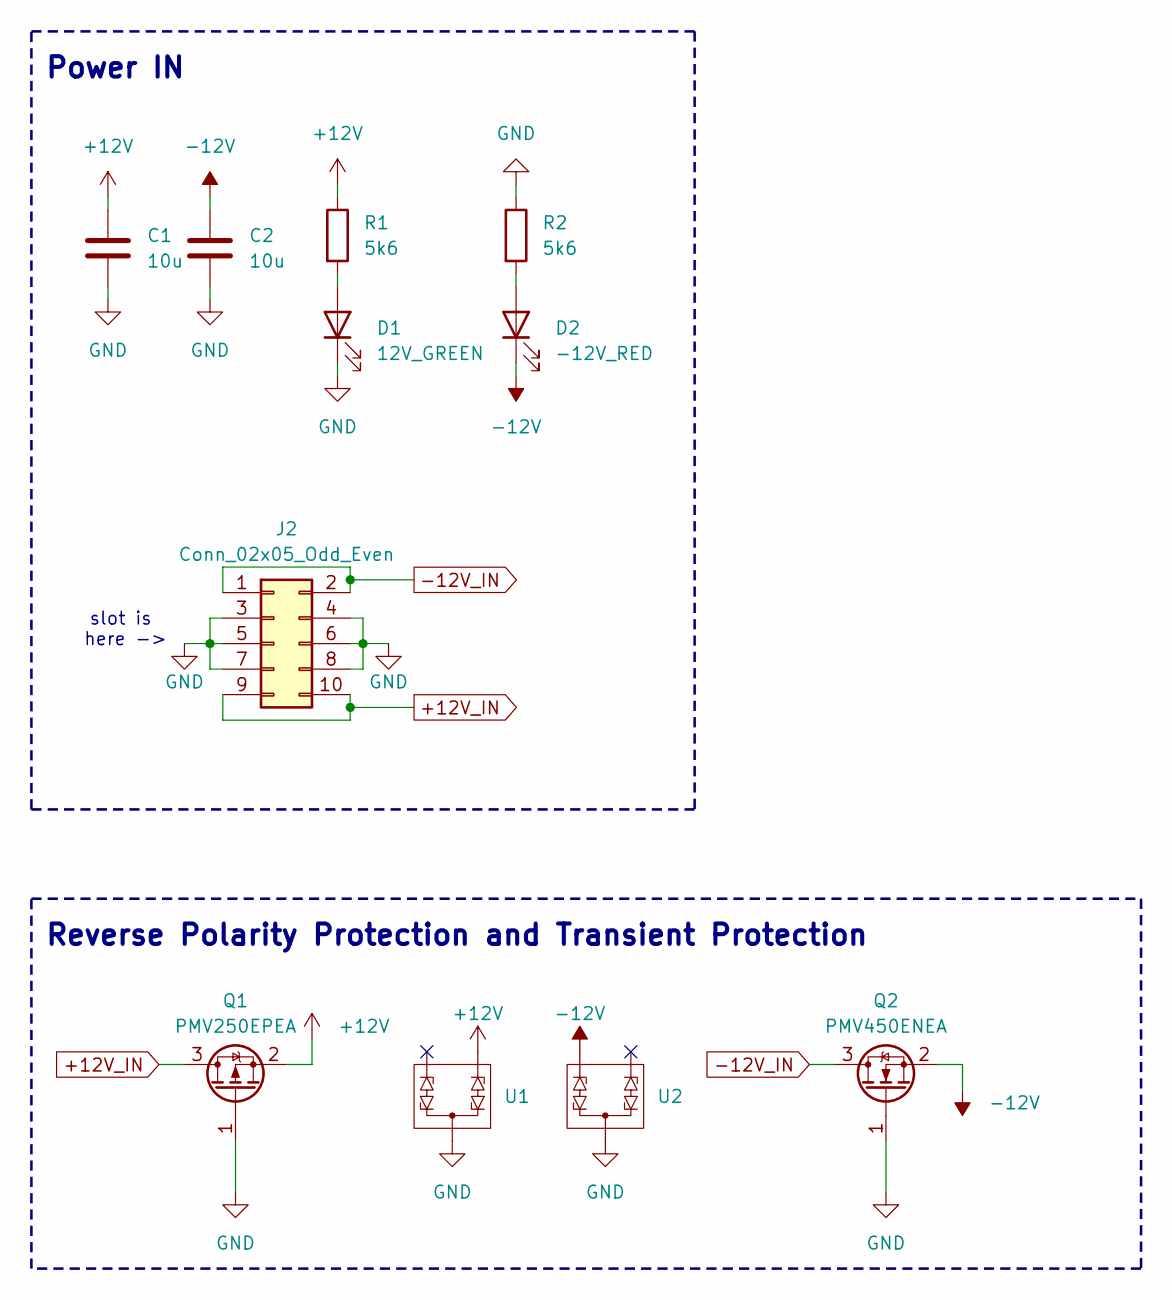
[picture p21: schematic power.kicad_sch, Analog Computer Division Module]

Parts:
C1, C2: 10u; C_1206_3216Metric_Pad1.33x1.80mm_HandSolder
D1: 12V_GREEN; LED_1206_3216Metric
D2: -12V_RED; LED_1206_3216Metric
J2: Conn_02x05_Odd_Even; PinHeader_2x05_P2.54mm_Vertical
Q1: PMV250EPEA; SOT-23_Handsoldering
Q2: PMV450ENEA; SOT-23_Handsoldering
R1, R2: 5k6; R_1206_3216Metric_Pad1.30x1.75mm_HandSolder
U1, U2: VCAN16A2; VCAN16A2-03S-E3-08

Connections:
+12V: C1.1, Q1.2 (S), R1.1, U1.1 (IN1); also elsewhere on the board
+12V_IN: J2.9, J2.10, Q1.3 (D); also elsewhere on the board
-12V: C2.1, D2.1 (K), Q2.2 (S), U2.2 (IN2); also elsewhere on the board
-12V_IN: J2.1, J2.2, Q2.3 (D); also elsewhere on the board
GND: C1.2, C2.2, D1.1 (K), J2.3, J2.4, J2.5, J2.6, J2.7, J2.8, Q1.1 (G), Q2.1 (G), R2.1, U1.3 (OUT), U2.3 (OUT); also elsewhere on the board
unnamed: D1.2 (A), R1.2
unnamed: D2.2 (A), R2.2

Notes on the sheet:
Reverse Polarity Protection and Transient Protection
Power IN
slot is here ->

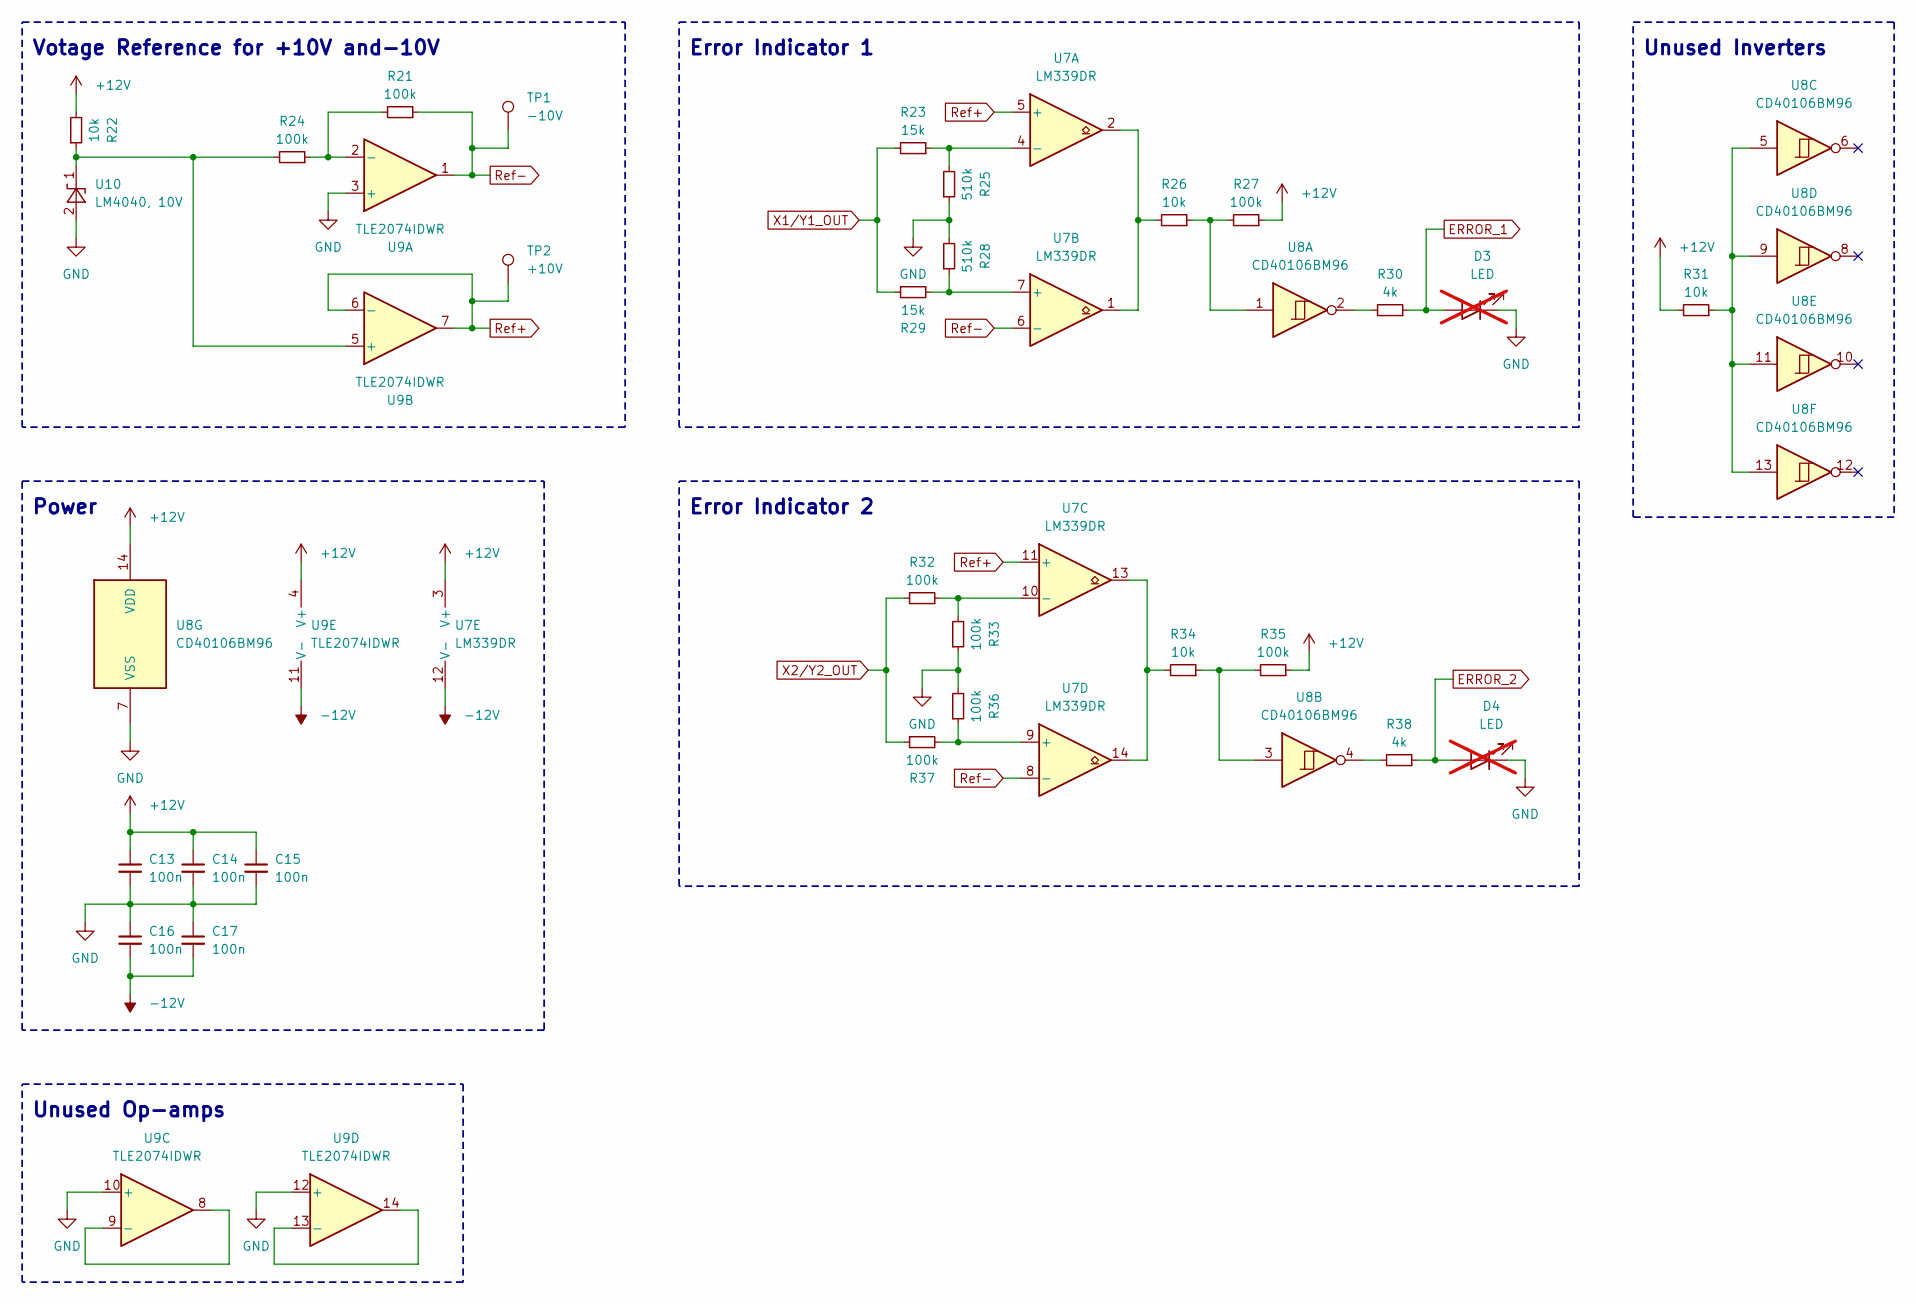
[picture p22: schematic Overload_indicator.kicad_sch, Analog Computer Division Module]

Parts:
C13, C14, C15, C16, C17: 100n; C_1206_3216Metric_Pad1.33x1.80mm_HandSolder
D3, D4: LED; not fitted
R21, R24, R27, R32, R33, R35, R36, R37: 100k; R_1206_3216Metric_Pad1.30x1.75mm_HandSolder
R22, R26, R31, R34: 10k; R_1206_3216Metric_Pad1.30x1.75mm_HandSolder
R23, R29: 15k; R_1206_3216Metric_Pad1.30x1.75mm_HandSolder
R25, R28: 510k; R_1206_3216Metric_Pad1.30x1.75mm_HandSolder
R30, R38: 4k; R_1206_3216Metric_Pad1.30x1.75mm_HandSolder
TP1: -10V; TestPoint_Pad_D2.0mm
TP2: +10V; TestPoint_Pad_D2.0mm
U7: LM339DR; SOIC-14_3.9x8.7mm_P1.27mm
U8: CD40106BM96; SOIC-14_3.9x8.7mm_P1.27mm
U9: TLE2074IDWR; SOIC-14_3.9x8.7mm_P1.27mm
U10: LM4040, 10V; SOT-23

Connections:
+12V: C13.1, C14.1, C15.1, R22.2, R27.1, R31.2, R35.1, U7.3 (V+), U8.14 (VDD), U9.4 (V+); also elsewhere on the board
-12V: C16.2, C17.2, U7.12 (V-), U9.11 (V-); also elsewhere on the board
ERROR_1: D3.2 (A), R30.1; also elsewhere on the board
ERROR_2: D4.2 (A), R38.1; also elsewhere on the board
GND: C13.2, C14.2, C15.2, C16.1, C17.1, D3.1 (K), D4.1 (K), R25.1, R28.2, R33.1, R36.2, U8.7 (VSS), U9.3 (+), U9.10 (+), U9.12 (+), U10.2 (A); also elsewhere on the board
unnamed: R26.1, R27.2, U8.1
unnamed: R26.2, U7.1, U7.2
unnamed: R30.2, U8.2
unnamed: R31.1, U8.5, U8.9, U8.11, U8.13
unnamed: R34.1, R35.2, U8.3
unnamed: R34.2, U7.13, U7.14
unnamed: R38.2, U8.4
unnamed: R23.1, R25.2, U7.4 (-)
unnamed: R28.1, R29.2, U7.7 (+)
unnamed: R32.1, R33.2, U7.10 (-)
unnamed: R36.1, R37.2, U7.9 (+)
unnamed: R21.2, R24.1, U9.2 (-)
unnamed: U9.8, U9.9 (-)
unnamed: U9.13 (-), U9.14
unnamed: R22.1, R24.2, U9.5 (+), U10.1 (K)
Ref+: TP2.1, U7.5 (+), U7.11 (+), U9.6 (-), U9.7
Ref-: R21.1, TP1.1, U7.6 (-), U7.8 (-), U9.1
X1/Y1_OUT: R23.2, R29.1; also elsewhere on the board
X2/Y2_OUT: R32.2, R37.1; also elsewhere on the board

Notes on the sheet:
Unused Inverters
Error Indicator 1
Unused Op-amps
Error Indicator 2
Power
Votage Reference for +10V and-10V

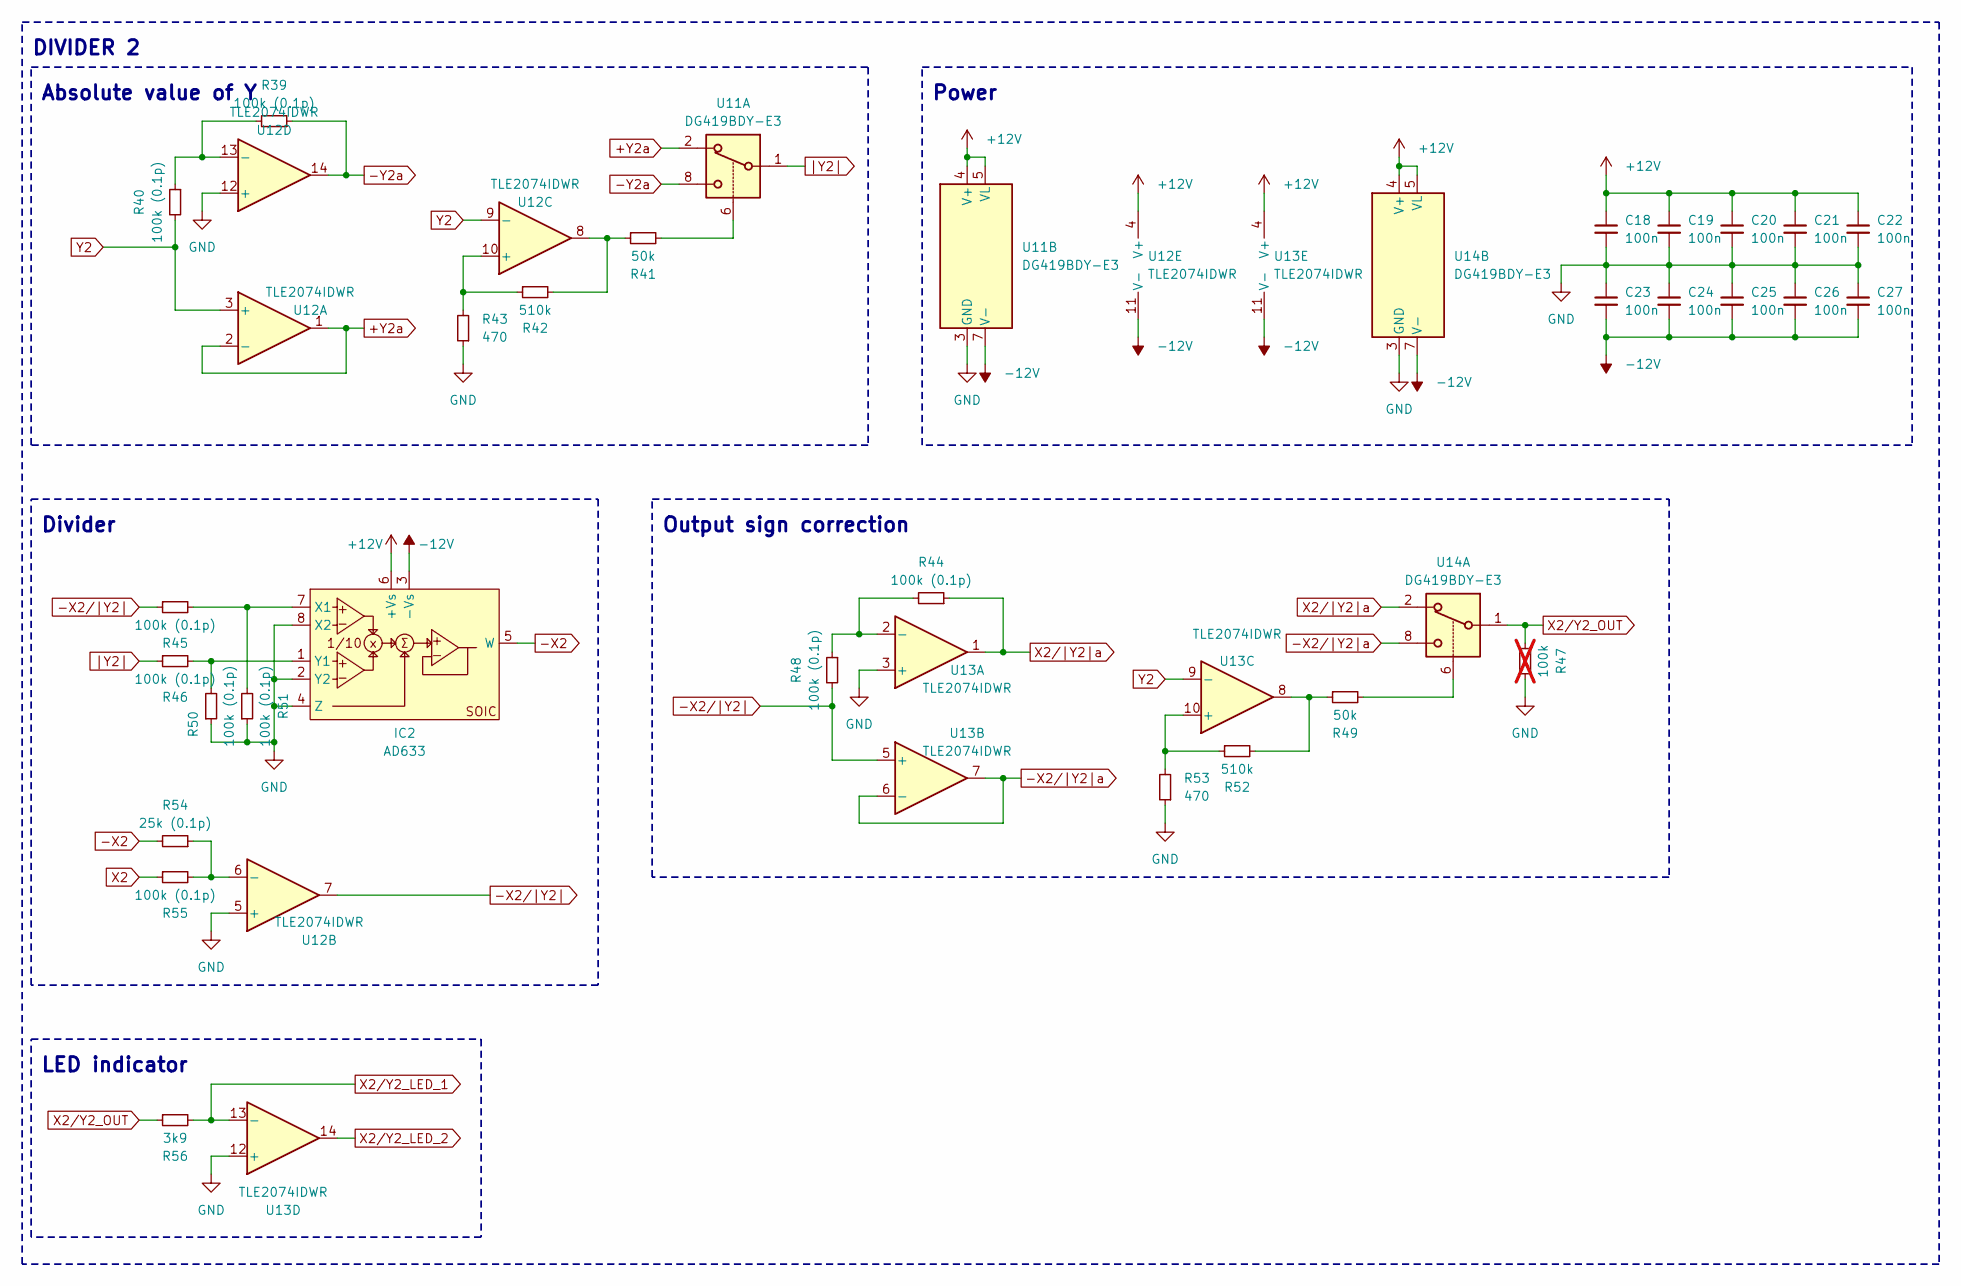
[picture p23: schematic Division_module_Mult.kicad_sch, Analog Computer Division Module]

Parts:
C18, C19, C20, C21, C22, C23, C24, C25, C26, C27: 100n; C_1206_3216Metric_Pad1.33x1.80mm_HandSolder
IC2: AD633; SOIC-8_3.9x4.9mm_P1.27mm
R39, R40, R44, R45, R46, R48, R50, R51, R55: 100k (0.1p); R_1206_3216Metric_Pad1.30x1.75mm_HandSolder
R41, R49: 50k; R_1206_3216Metric_Pad1.30x1.75mm_HandSolder
R42, R52: 510k; R_1206_3216Metric_Pad1.30x1.75mm_HandSolder
R43, R53: 470; R_1206_3216Metric_Pad1.30x1.75mm_HandSolder
R47: 100k; R_1206_3216Metric_Pad1.30x1.75mm_HandSolder; not fitted
R54: 25k (0.1p); R_1206_3216Metric_Pad1.30x1.75mm_HandSolder
R56: 3k9; R_1206_3216Metric_Pad1.30x1.75mm_HandSolder
U11, U14: DG419BDY-E3; SOIC-8_3.9x4.9mm_P1.27mm
U12, U13: TLE2074IDWR; SOIC-14_3.9x8.7mm_P1.27mm

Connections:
+12V: C18.1, C19.1, C20.1, C21.1, C22.1, IC2.6 (+Vs), U11.4 (V+), U11.5 (VL), U12.4 (V+), U13.4 (V+), U14.4 (V+), U14.5 (VL); also elsewhere on the board
+Y2a: U11.2, U12.1, U12.2 (-)
-12V: C23.2, C24.2, C25.2, C26.2, C27.2, IC2.3 (-Vs), U11.7 (V-), U12.11 (V-), U13.11 (V-), U14.7 (V-); also elsewhere on the board
-X2: IC2.5 (W), R54.2
-X2/|Y2|: R45.1, R48.2, U12.7, U13.5 (+)
-X2/|Y2|a: U13.6 (-), U13.7, U14.8
-Y2a: R39.1, U11.8, U12.14
GND: C18.2, C19.2, C20.2, C21.2, C22.2, C23.1, C24.1, C25.1, C26.1, C27.1, IC2.2 (Y2), IC2.4 (Z), IC2.8 (X2), R43.1, R47.1, R50.1, R51.1, R53.1, U11.3 (GND), U12.5 (+), U12.12 (+), U13.3 (+), U13.12 (+), U14.3 (GND); also elsewhere on the board
unnamed: IC2.7 (X1), R45.2, R51.2
unnamed: IC2.1 (Y1), R46.2, R50.2
unnamed: R41.1, R42.2, U12.8
unnamed: R41.2, U11.6
unnamed: R49.1, R52.2, U13.8
unnamed: R49.2, U14.6
unnamed: R54.1, R55.2, U12.6 (-)
unnamed: R42.1, R43.2, U12.10 (+)
unnamed: R39.2, R40.1, U12.13 (-)
unnamed: R44.2, R48.1, U13.2 (-)
unnamed: R52.1, R53.2, U13.10 (+)
X2: R55.1; also elsewhere on the board
X2/Y2_LED_1: R56.2, U13.13 (-); also elsewhere on the board
X2/Y2_LED_2: U13.14; also elsewhere on the board
X2/Y2_OUT: R47.2, R56.1, U14.1; also elsewhere on the board
X2/|Y2|a: R44.1, U13.1, U14.2
Y2: R40.2, U12.3 (+), U12.9 (-), U13.9 (-); also elsewhere on the board
|Y2|: R46.1, U11.1

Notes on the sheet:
Absolute value of Y
LED indicator
Divider
Power
Output sign correction
DIVIDER 2

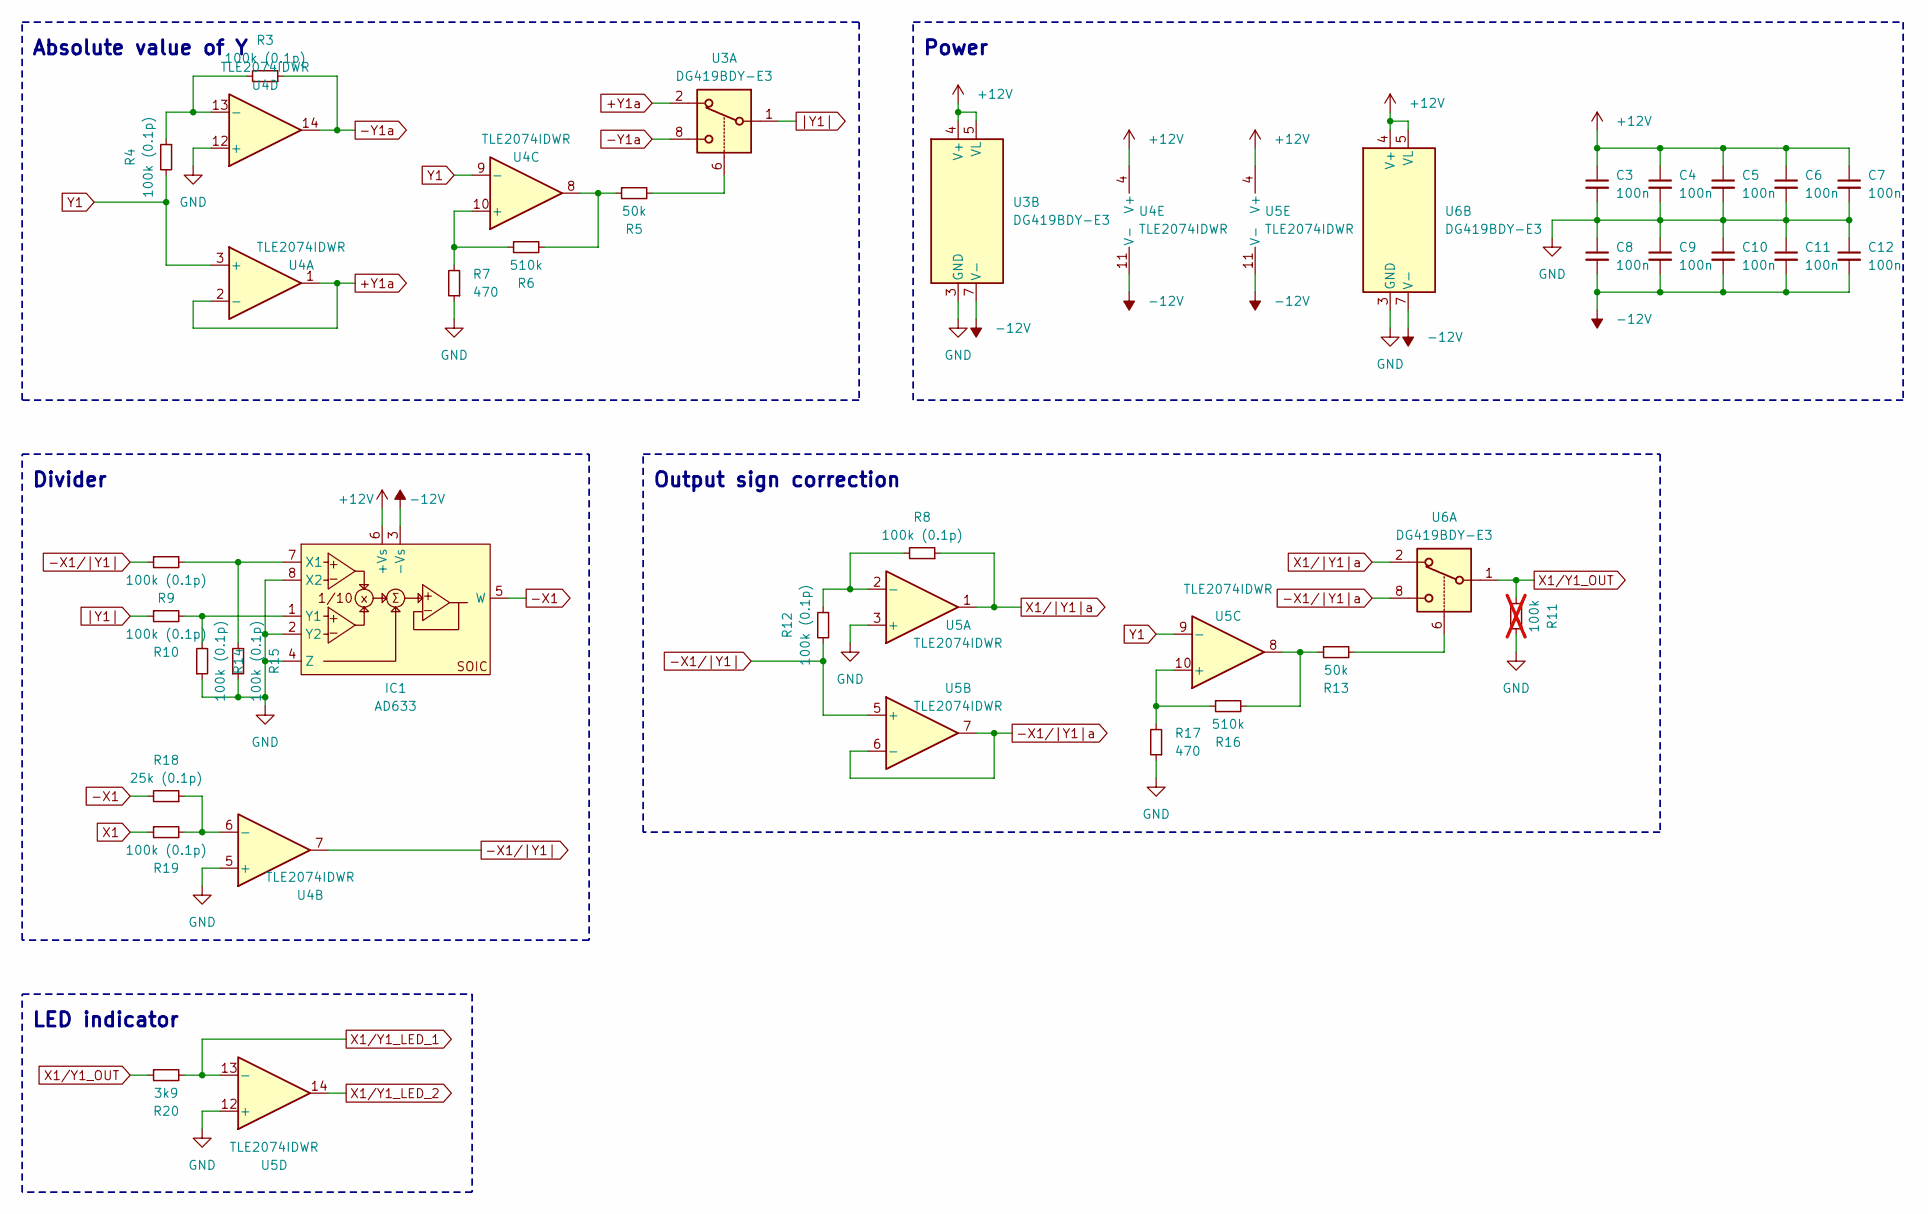
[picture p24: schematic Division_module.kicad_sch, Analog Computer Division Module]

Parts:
C3, C4, C5, C6, C7, C8, C9, C10, C11, C12: 100n; C_1206_3216Metric_Pad1.33x1.80mm_HandSolder
IC1: AD633; SOIC-8_3.9x4.9mm_P1.27mm
R3, R4, R8, R9, R10, R12, R14, R15, R19: 100k (0.1p); R_1206_3216Metric_Pad1.30x1.75mm_HandSolder
R5, R13: 50k; R_1206_3216Metric_Pad1.30x1.75mm_HandSolder
R6, R16: 510k; R_1206_3216Metric_Pad1.30x1.75mm_HandSolder
R7, R17: 470; R_1206_3216Metric_Pad1.30x1.75mm_HandSolder
R11: 100k; R_1206_3216Metric_Pad1.30x1.75mm_HandSolder; not fitted
R18: 25k (0.1p); R_1206_3216Metric_Pad1.30x1.75mm_HandSolder
R20: 3k9; R_1206_3216Metric_Pad1.30x1.75mm_HandSolder
U3, U6: DG419BDY-E3; SOIC-8_3.9x4.9mm_P1.27mm
U4, U5: TLE2074IDWR; SOIC-14_3.9x8.7mm_P1.27mm

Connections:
+12V: C3.1, C4.1, C5.1, C6.1, C7.1, IC1.6 (+Vs), U3.4 (V+), U3.5 (VL), U4.4 (V+), U5.4 (V+), U6.4 (V+), U6.5 (VL); also elsewhere on the board
+Y1a: U3.2, U4.1, U4.2 (-)
-12V: C8.2, C9.2, C10.2, C11.2, C12.2, IC1.3 (-Vs), U3.7 (V-), U4.11 (V-), U5.11 (V-), U6.7 (V-); also elsewhere on the board
-X1: IC1.5 (W), R18.2
-X1/|Y1|: R9.1, R12.2, U4.7, U5.5 (+)
-X1/|Y1|a: U5.6 (-), U5.7, U6.8
-Y1a: R3.1, U3.8, U4.14
GND: C3.2, C4.2, C5.2, C6.2, C7.2, C8.1, C9.1, C10.1, C11.1, C12.1, IC1.2 (Y2), IC1.4 (Z), IC1.8 (X2), R7.1, R11.1, R14.1, R15.1, R17.1, U3.3 (GND), U4.5 (+), U4.12 (+), U5.3 (+), U5.12 (+), U6.3 (GND); also elsewhere on the board
unnamed: IC1.7 (X1), R9.2, R15.2
unnamed: IC1.1 (Y1), R10.2, R14.2
unnamed: R5.1, R6.2, U4.8
unnamed: R5.2, U3.6
unnamed: R13.1, R16.2, U5.8
unnamed: R13.2, U6.6
unnamed: R18.1, R19.2, U4.6 (-)
unnamed: R6.1, R7.2, U4.10 (+)
unnamed: R3.2, R4.1, U4.13 (-)
unnamed: R8.2, R12.1, U5.2 (-)
unnamed: R16.1, R17.2, U5.10 (+)
X1: R19.1; also elsewhere on the board
X1/Y1_LED_1: R20.2, U5.13 (-); also elsewhere on the board
X1/Y1_LED_2: U5.14; also elsewhere on the board
X1/Y1_OUT: R11.2, R20.1, U6.1; also elsewhere on the board
X1/|Y1|a: R8.1, U5.1, U6.2
Y1: R4.2, U4.3 (+), U4.9 (-), U5.9 (-); also elsewhere on the board
|Y1|: R10.1, U3.1

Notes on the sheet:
Divider
Power
Absolute value of Y
Output sign correction
LED indicator

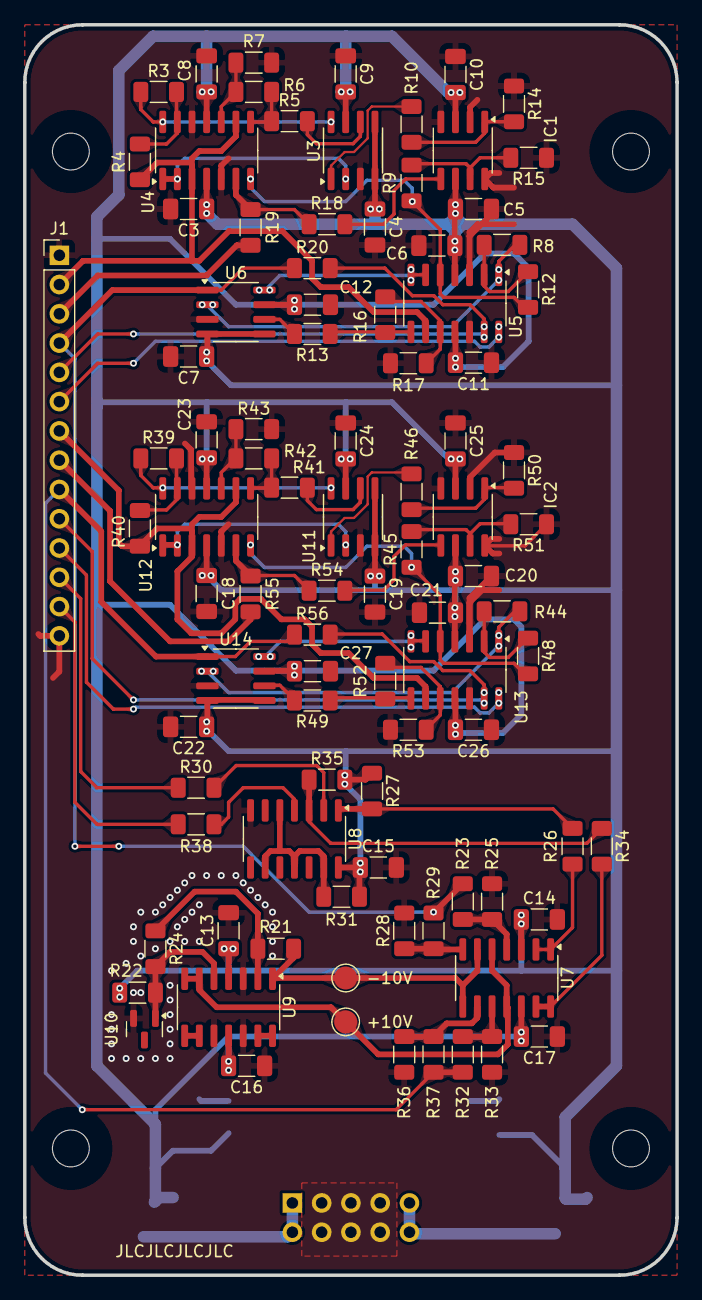
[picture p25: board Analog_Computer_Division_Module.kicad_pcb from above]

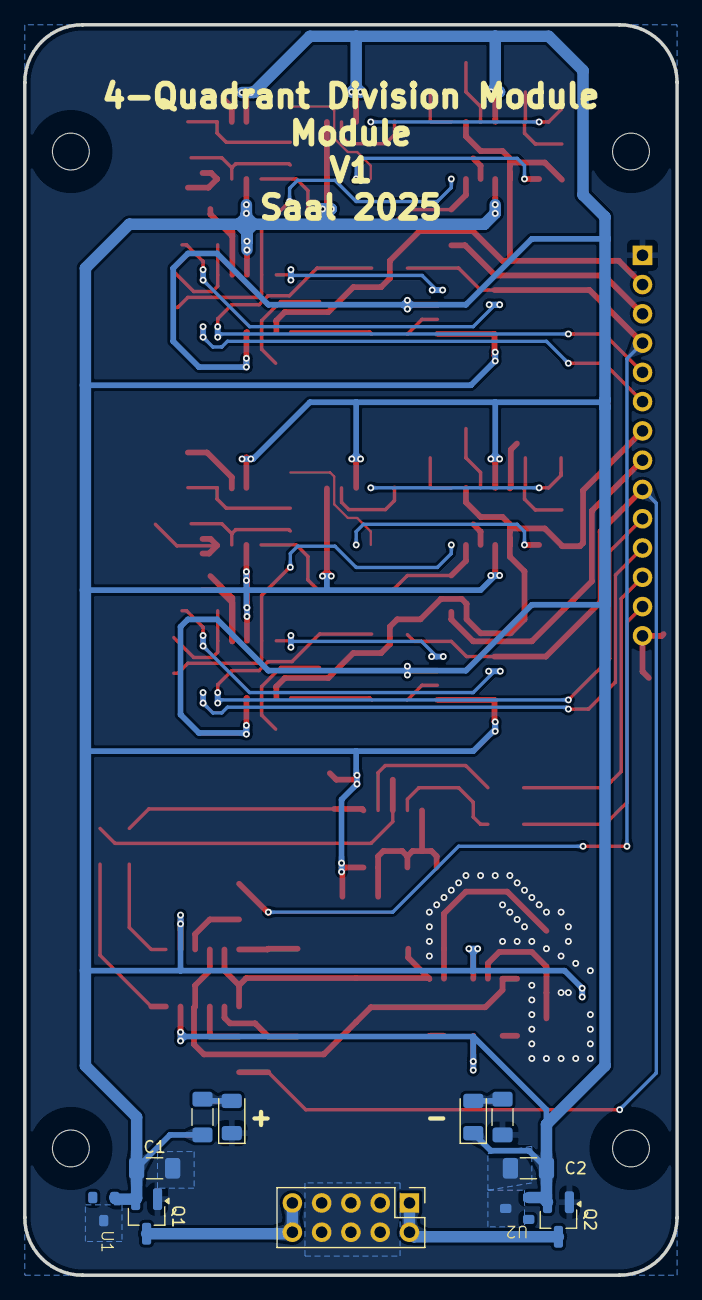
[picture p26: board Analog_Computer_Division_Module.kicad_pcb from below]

Board: 2 copper layers, 56.6 x 108.5 mm, 109 parts (11 on the bottom side), 72 nets.

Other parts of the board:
J3: Conn_02x05_Odd_Even; PinHeader_2x05_P2.54mm_Vertical

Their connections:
+12V_IN: J3.9, J3.10; also elsewhere on the board
-12V_IN: J3.1, J3.2; also elsewhere on the board
GND: J3.3, J3.4, J3.5, J3.6, J3.7, J3.8; also elsewhere on the board

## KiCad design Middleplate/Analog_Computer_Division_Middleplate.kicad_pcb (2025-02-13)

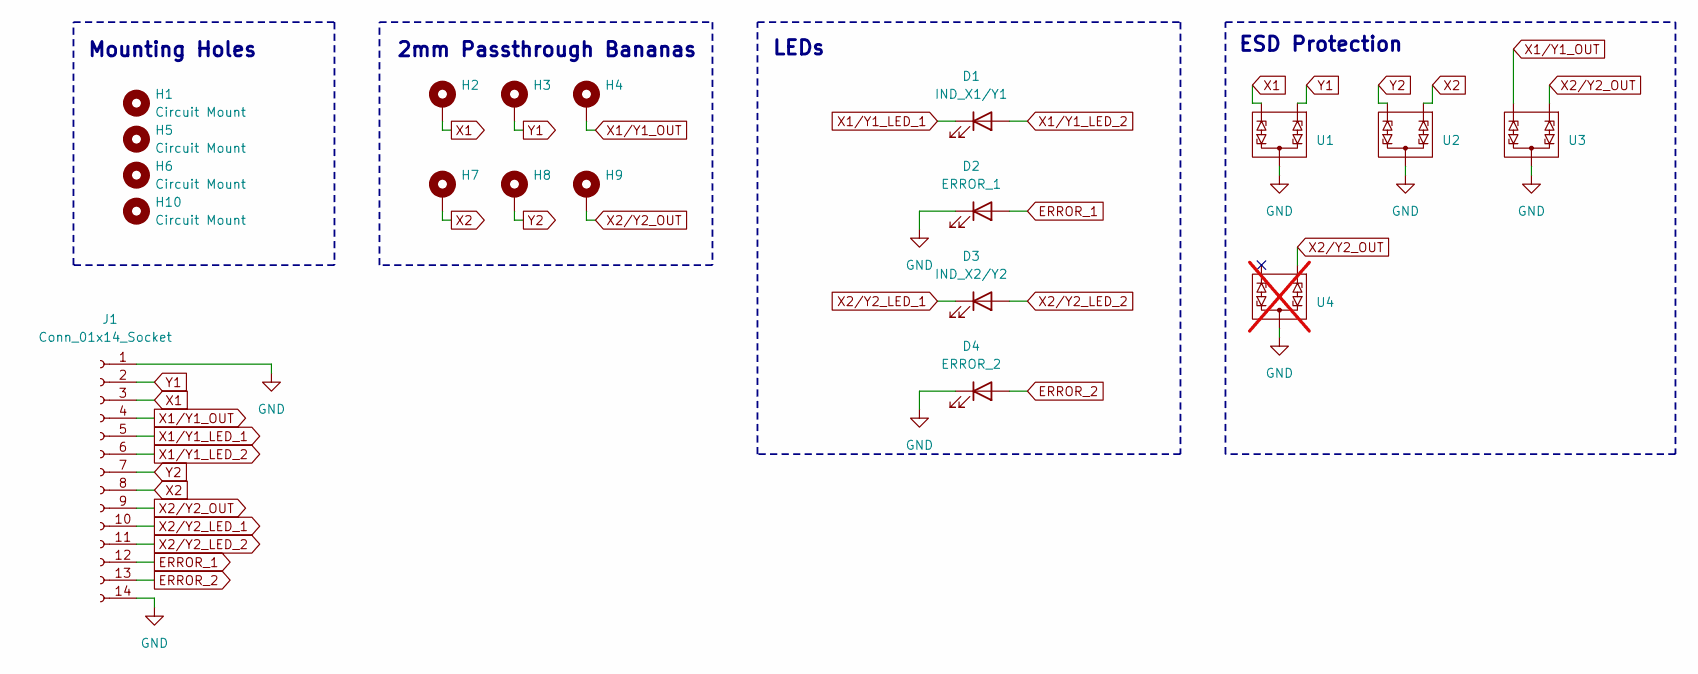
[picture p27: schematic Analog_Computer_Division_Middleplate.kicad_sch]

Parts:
D1: IND_X1/Y1; LED_D3.0mm_FlatTop
D2: ERROR_1; LED_D3.0mm_FlatTop
D3: IND_X2/Y2; LED_D3.0mm_FlatTop
D4: ERROR_2; LED_D3.0mm_FlatTop
H1, H5, H6, H10: Circuit Mount; MountingHole_3.2mm_M3_DIN965
H2: X1; MountingHole_4.3mm_M4_DIN965_Pad
H3: Y1; MountingHole_4.3mm_M4_DIN965_Pad
H4: X1/Y1; MountingHole_4.3mm_M4_DIN965_Pad
H7: X2; MountingHole_4.3mm_M4_DIN965_Pad
H8: Y2; MountingHole_4.3mm_M4_DIN965_Pad
H9: X2/Y2; MountingHole_4.3mm_M4_DIN965_Pad
J1: Conn_01x14_Socket; PinSocket_1x14_P2.54mm_Vertical
U1, U2, U3: VCAN16A2-03S-E3-08
U4: VCAN16A2-03S-E3-08; not fitted

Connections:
ERROR_1: D2.2 (A), J1.12
ERROR_2: D4.2 (A), J1.13
GND: D2.1 (K), D4.1 (K), J1.1, J1.14, U1.3 (OUT), U2.3 (OUT), U3.3 (OUT), U4.3 (OUT)
X1: H2.1, J1.3, U1.2 (IN2)
X1/Y1_LED_1: D1.1 (K), J1.5
X1/Y1_LED_2: D1.2 (A), J1.6
X1/Y1_OUT: H4.1, J1.4, U3.2 (IN2)
X2: H7.1, J1.8, U2.1 (IN1)
X2/Y2_LED_1: D3.1 (K), J1.10
X2/Y2_LED_2: D3.2 (A), J1.11
X2/Y2_OUT: H9.1, J1.9, U3.1 (IN1), U4.1 (IN1)
Y1: H3.1, J1.2, U1.1 (IN1)
Y2: H8.1, J1.7, U2.2 (IN2)

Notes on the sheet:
ESD Protection
Mounting Holes
2mm Passthrough Bananas
LEDs

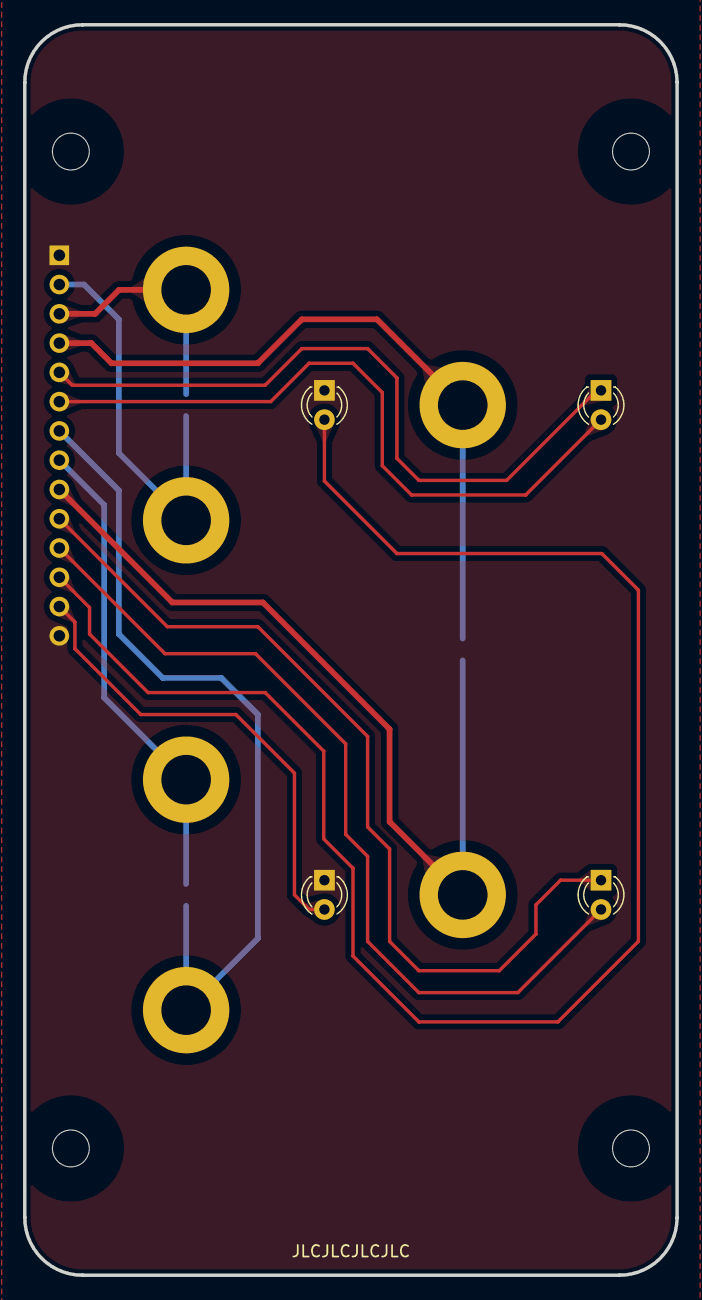
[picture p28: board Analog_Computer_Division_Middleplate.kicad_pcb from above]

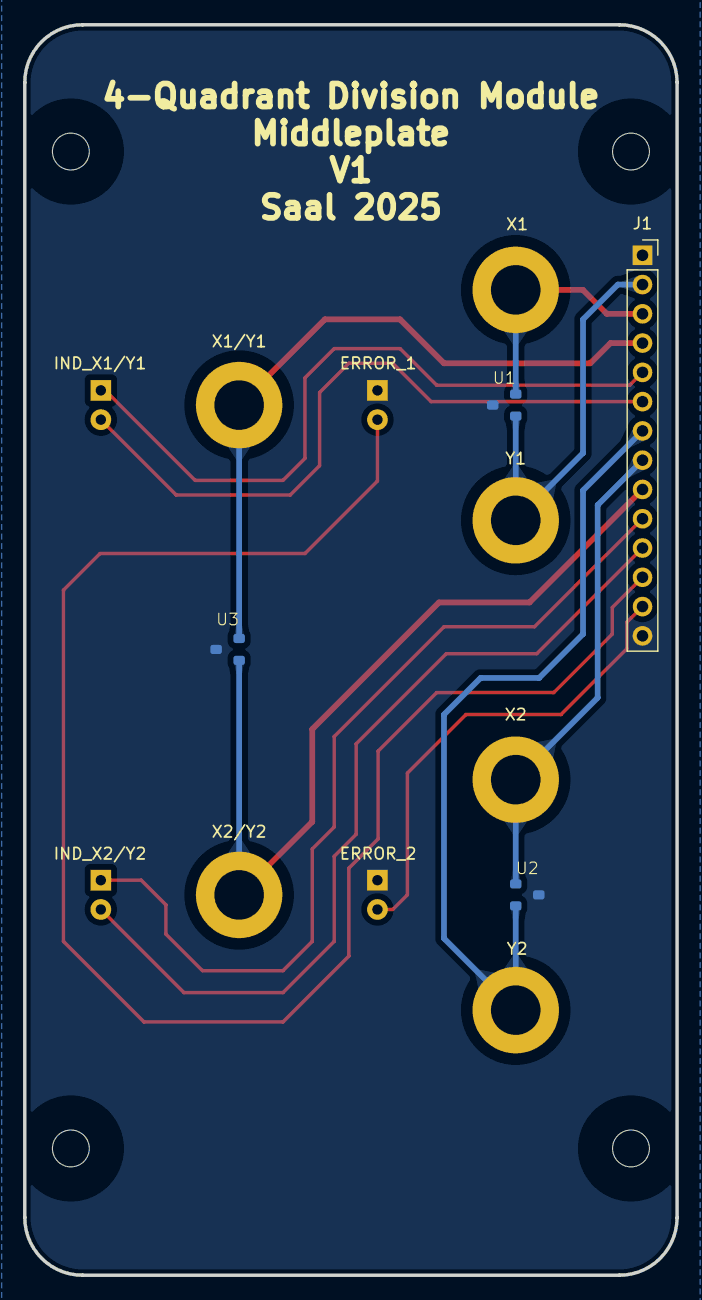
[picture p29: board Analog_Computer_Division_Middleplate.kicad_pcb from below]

Board: 2 copper layers, 56.6 x 108.5 mm, 18 parts (5 on the bottom side), 13 nets.

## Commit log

2025-01-20 finished V1
    [Analog_Computer_Division_Frontplate.kicad_pcb, Analog_Computer_Division_Frontplate.kicad_sch, Analog_Computer_Division_Middleplate.kicad_pcb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]
2025-02-13 cleaned up design and updated README
    [Analog_Computer_Division_Frontplate_BOM.csv, Analog_Computer_Division_Middleplate.kicad_pcb, Analog_Computer_Division_Middleplate.kicad_sch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]
